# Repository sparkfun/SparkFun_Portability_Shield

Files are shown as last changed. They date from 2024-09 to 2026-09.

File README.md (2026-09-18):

SparkFun Portability Shield
========================================

SparkFun Portability Shield (https://www.sparkfun.com/products/27510)

[*SparkFun Portability Shield (DEV-27510)*](https://www.sparkfun.com/products/27510)

The SparkFun Portability Shield adds all the user interface bits needed to take a SparkFun development board into the field. A LiPo battery connector, charger, fuel gauge, and an on/off switch address your power needs. A friction-fit microSD connector allows for data logging. The 1.3in. OLED and a five-way navigation switch provide an excellent user interface. Locking 0.1in. headers along the shield's edge make it easier to solder male pins in place.

I<sup>2</sup>C is used to interface with the display, fuel gauge, and five-way navigation switch (GPIO expander PCA9554). SPI is used to communicate with the microSD card. The power switch uses an ideal diode (LM66200) to disconnect the battery from the system for a sleep current of approximately 4μA.

The Portability Shield has been designed to be usable with any compatible main board, with the [RTK Postcard](https://www.sparkfun.com/products/26916) being the first!

Head to the [Sparkfun Portability Shield Product Manual](http://docs.sparkfun.com/SparkFun_Portability_Shield/) for technical documentation.

Repository Contents
-------------------

* **/Hardware** - KiCad design files (.kicad_pro, .kicad_pcb, kicad_sch)
* **/docs** - Documentation for the github pages version of this hookup guide

License Information
-------------------

This product is _**open source**_!

Please review the LICENSE.md file for license information.

If you have any questions or concerns on licensing, please contact technical support on our [SparkFun forums](https://community.sparkfun.com).

Distributed as-is; no warranty is given.

- Your friends at SparkFun.

_<COLLABORATION CREDIT>_

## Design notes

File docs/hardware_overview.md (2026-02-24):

---
icon: material/cog
---

## OLED
The 1.3" OLED is a small, monochrome, blue on black display with a 128 x 64 dot matrix panel and a 7-bit unshifted I<sup>2</sup>C address of 0x3D. To change the I<sup>2</sup>C address to 0x3C, cut the D/C jumper on the back of the board. For more information, refer to the [datasheet](https://cdn.sparkfun.com/assets/learn_tutorials/3/0/8/SSD1306.pdf).

<figure markdown>
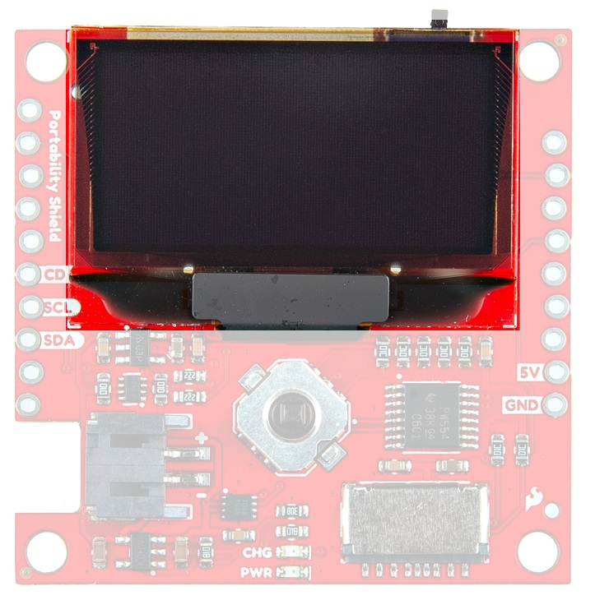
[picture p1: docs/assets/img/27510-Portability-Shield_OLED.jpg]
1.3" OLED Screen

<figcaption markdown>1.3" OLED Screen</figcaption>
</figure>

## Navigation Switch

The Navigation Switch allows for navigation of the configuration modes and menus related to the RTK or other loaded software.

<figure markdown>
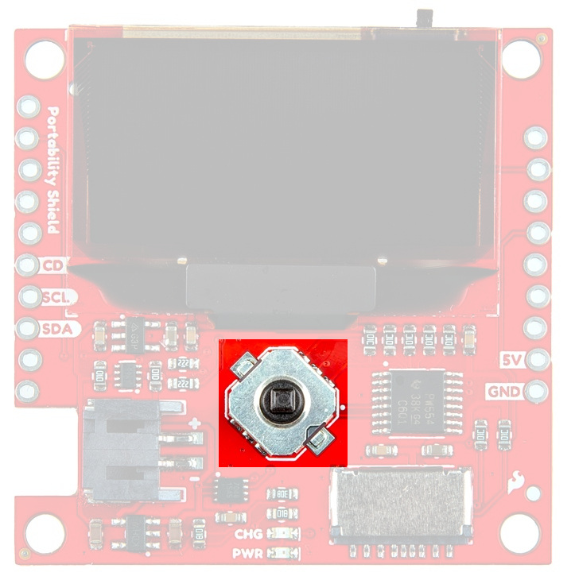
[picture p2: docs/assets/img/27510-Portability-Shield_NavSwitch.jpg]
Navigation Switch

<figcaption markdown>Navigation Switch</figcaption>
</figure>

## GPIO Expander

The TCA9554 GPIO Expander is used for I<sup>2</sup>C interfacing with the Navigation Switch, 1.3" OLED display, the fuel gauge, and the SD Card Detect. Its 7-bit unshifted address is 0x20.

<figure markdown>
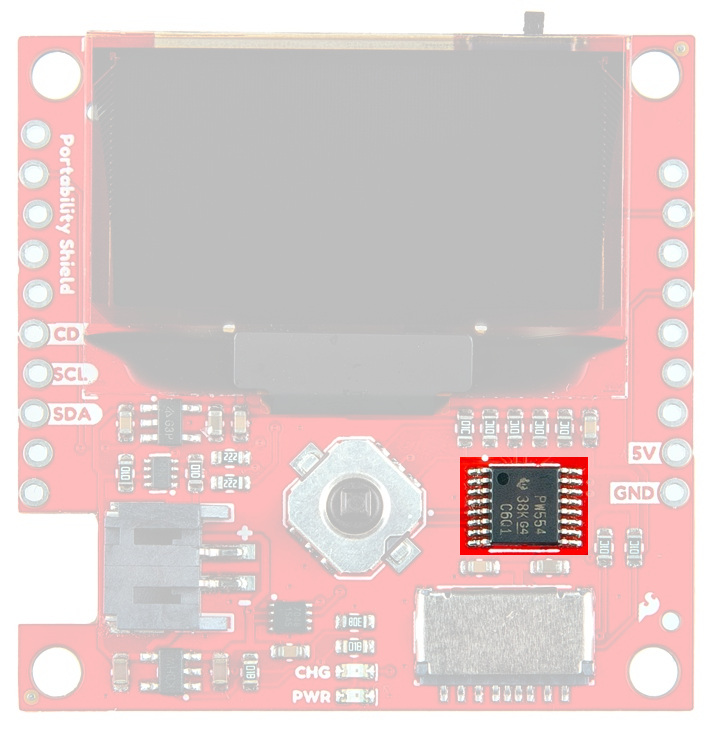
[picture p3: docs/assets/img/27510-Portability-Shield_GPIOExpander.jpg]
GPIO Expander

<figcaption markdown>GPIO Expander</figcaption>
</figure>

## Power

Power is provided by either the LiPo Battery or the 5V/GND pins. Maximum input to the board is 5V.

<figure markdown>
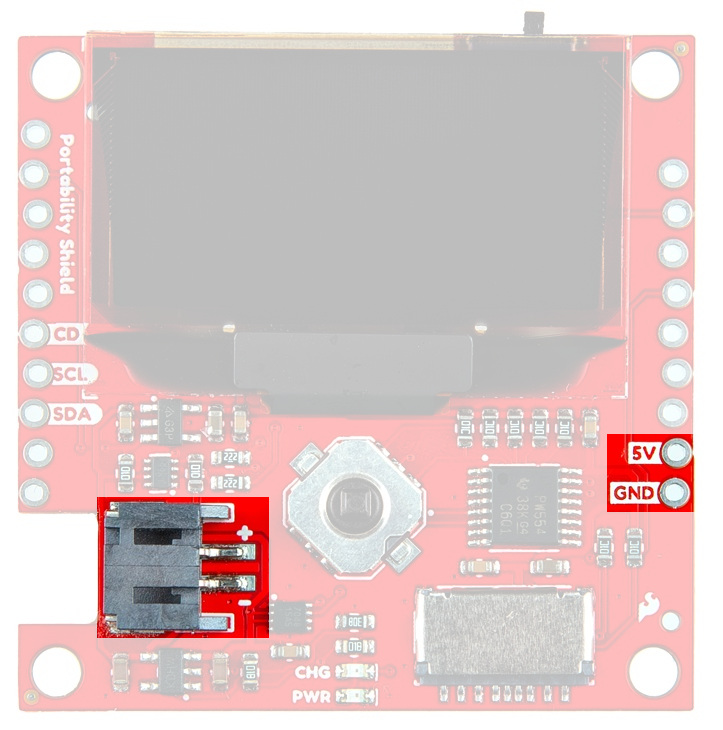
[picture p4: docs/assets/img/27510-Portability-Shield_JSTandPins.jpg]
Battery Connector/Power Pins

<figcaption markdown>Battery Connector/Power Pins</figcaption>
</figure>

## Current Measurement

There are two plated through holes available on the bottom of the board to measure current if desired.

<figure markdown>
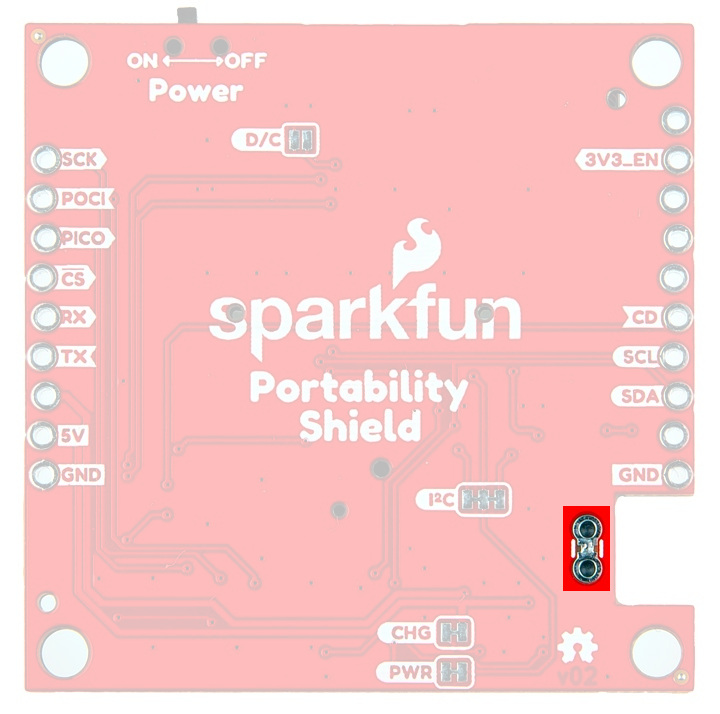
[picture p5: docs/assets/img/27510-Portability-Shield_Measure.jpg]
Current Measurement PTHs

<figcaption markdown>Current Measurement PTHs</figcaption>
</figure>

## On/Off Switch

How handy! There is an On/Off switch at the top of the board.

<figure markdown>
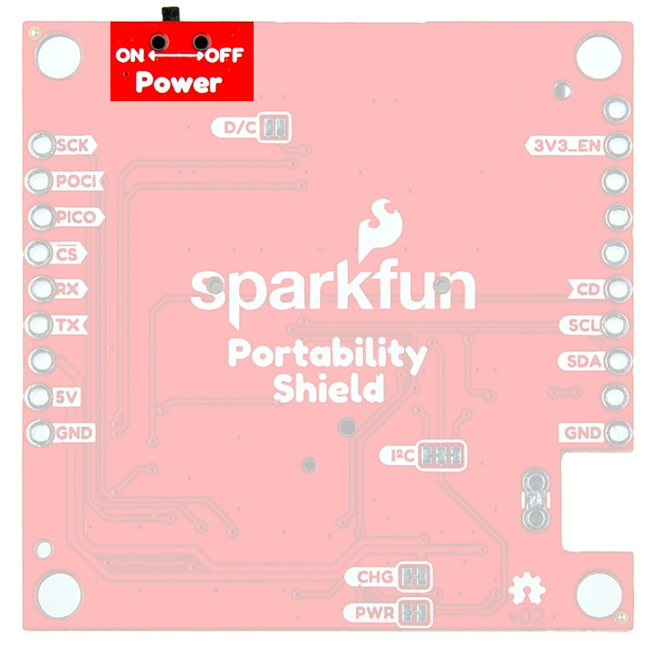
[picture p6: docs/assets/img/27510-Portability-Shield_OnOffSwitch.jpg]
On/Off Switch

<figcaption markdown>On/Off Switch</figcaption>
</figure>

## Fuel Gauge

The MAX17048 uses the Li+ battery-modeling algorithm ModelGauge™ to track the battery relative state-of-charge (SOC) continuously over widely varying charge and discharge conditions. This eliminates current-sense resistor and battery learn cycles required in traditional fuel gauges and allows for the most accurate battery percentage readings. Its 7-bit unshifted address is 0x36. For more information, you can refer to the [datasheet](https://cdn.sparkfun.com/assets/5/2/7/6/6/MAX17048-MAX17049.pdf).

<figure markdown>
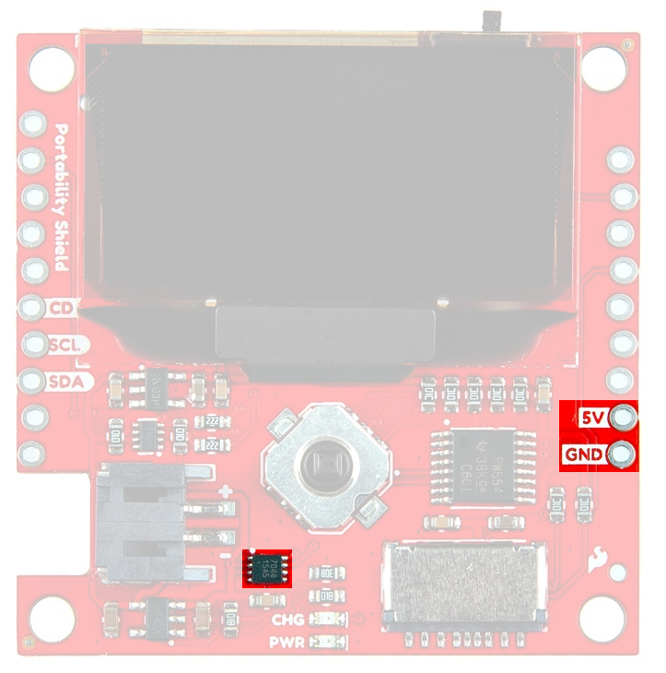
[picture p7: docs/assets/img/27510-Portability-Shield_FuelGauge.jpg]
Fuel Gauge

<figcaption markdown>Fuel Gauge</figcaption>
</figure>

## LiPo Charging Circuit

The charge circuit charges Li+ batteries at 500mA. The equation below shows our calculation for this rate.

<figure markdown>
Charge Circuit Equation
<figcaption markdown>Charge Circuit</figcaption>
</figure>

## MicroSD Card

The microSD Socket Friction Fit slot allows for data logging or easy upload of programming files.

!!! warning
	Do NOT drive the microSD card pins high if the card is not powered. Damage could occur!

<figure markdown>
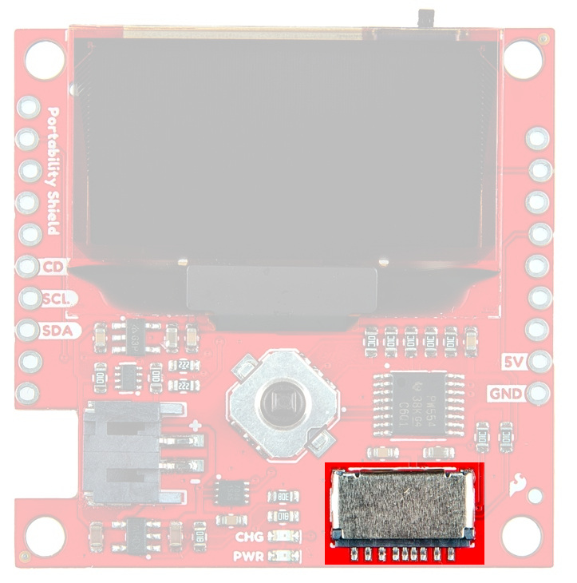
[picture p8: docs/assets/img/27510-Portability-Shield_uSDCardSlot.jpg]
microSD Card Slot

<figcaption markdown>microSD Card Slot</figcaption>
</figure>

<!-- ## Battery Charging Circuit

<figure markdown>
[![Charge Circuit Equation](assets/img/chargeCircuitEquations.jpg){ width="75%" }](assets/img/chargeCircuitEquations.jpg "Click to enlarge")
<figcaption markdown>Charge Circuit</figcaption>
</figure>

-->

## Shield Connectors

The offset PTHs allow for a snug fit when soldering headers to the board. Once male headers are soldered in, the SparkFun Portability Shield can be fit to the main board of choice.

If <b>5V</b> is present, LiPo charging commences. Below <b>5V</b>, the battery will provide VBATT to the mainboard 3.3V is not provided to mainboard - 5V/VBATT powers local 3.3V_P.

<figure markdown>
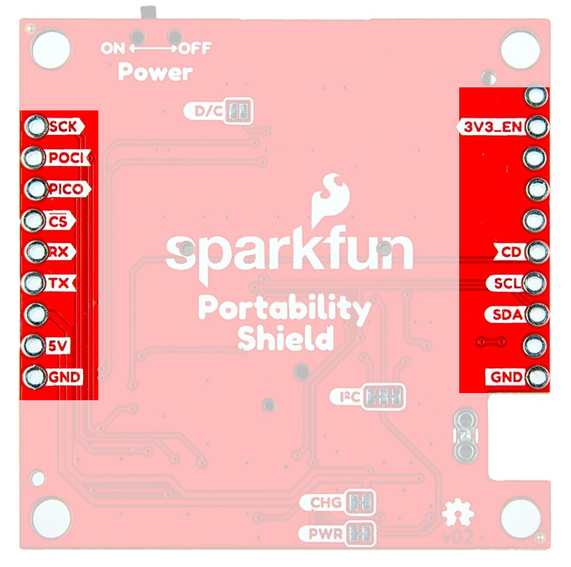
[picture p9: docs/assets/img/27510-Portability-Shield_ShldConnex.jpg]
Shield Connectors

<figcaption markdown>Shield Connectors</figcaption>
</figure>

## Jumpers

* <b>CHG:</b>
    Cutting this jumper will disconnect the power to the CHG LED on the front of the board.

* <b>PWR:</b>
    Cutting this jumper will disconnect the power to the PWR LED on the front of the board.

* <b>D/C:</b>
    Cutting this jumper will change the I<sup>2</sup>C address from 0x3D to 0x3C.
<div style="text-align: center;">
    <table>
        <tr>
            <th style="text-align: center; border: solid 1px #cccccc;">D/C
            </th>
            <th style="text-align: center; border: solid 1px #cccccc;">I2C Addr
            </th>
        </tr>
        <tr>
            <td style="text-align: center; border: solid 1px #cccccc;">0
            </td>
            <td style="text-align: center; border: solid 1px #cccccc;">0x3C
            </td>
        </tr>
        <tr>
            <td style="text-align: center; border: solid 1px #cccccc;">1
            </td>
            <td style="text-align: center; border: solid 1px #cccccc;">0x3D (default)
            </td>
        </tr>
    </table>
</div>
* <b>I<sup>2</sup>C:</b>
	The SparkFun Portability Shield has built-in 2.2k pull-up resistors on the SDA and SCL lines. These are needed for normal I<sup>2</sup>C communication. The I<sup>2</sup>C jumper has two small traces connecting the pull-ups to 3.3V. **For general use you can leave this jumper unmodified.** If you have many (over 7) devices on the I<sup>2</sup>C bus, each with their own pull up resistors, then you may want to [cut the I<sup>2</sup>C jumpers](https://learn.sparkfun.com/tutorials/how-to-work-with-jumper-pads-and-pcb-traces) to disconnect the 2.2k resistors on each Qwiic board.

<figure markdown>
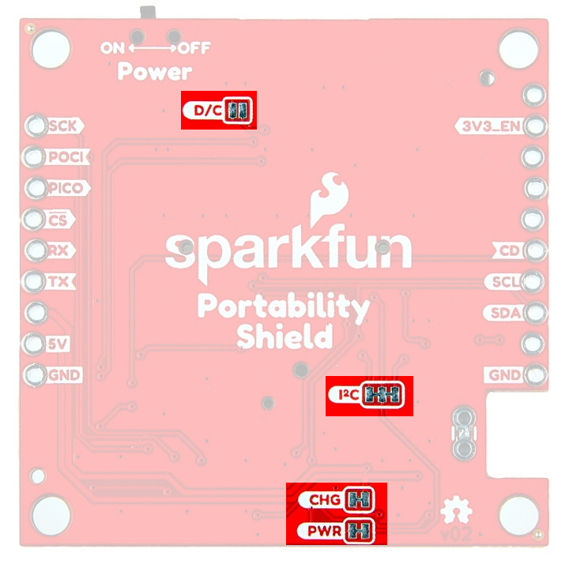
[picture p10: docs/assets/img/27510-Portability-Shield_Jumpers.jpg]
Jumpers

<figcaption markdown>Jumpers</figcaption>
</figure>

## Board Dimensions

The board dimensions are illustrated in the drawing below; the listed measurements are in millimeters.

<figure markdown>
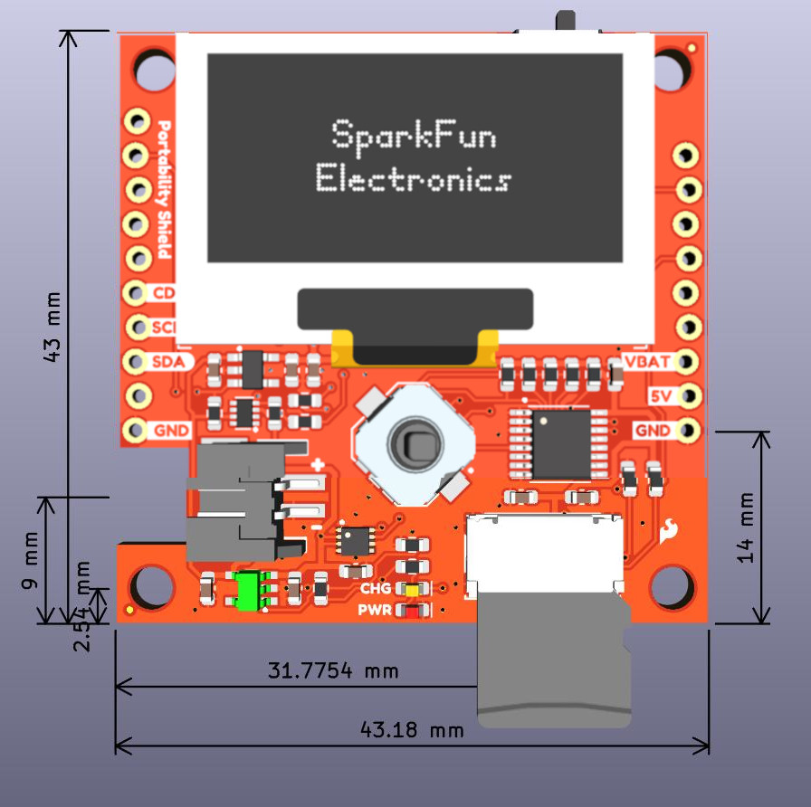
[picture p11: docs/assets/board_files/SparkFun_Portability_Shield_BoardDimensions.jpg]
Board measures 43.18mm x 43mm

<figcaption markdown>SparkFun Portability Shield Board Dimensions</figcaption>
</figure>

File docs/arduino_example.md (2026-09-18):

---
icon: simple/arduino
---

###Example 1: Navigation Switch

This example demonstrates how to use the navigation switch and detect if the SD card is inserted. The !INT pin of the GPIO expander IC (PCA9554) triggers an interrupt any time a button is pressed or an SD card is inserted/removed.

The code for this example can be found in the [Firmware](../Firmware/Example1_NavigationSwitch/) folder of this repository. Alternatively, you can expand the link below and copy and paste the code into a shiny new Arduino sketch:

??? "Example 1 Arduino Code"
	```cpp
	--8<-- "https://raw.githubusercontent.com/sparkfun/SparkFun_Portability_Shield/refs/heads/main/Firmware/Example1_NavigationSwitch/Example1_NavigationSwitch.ino"
	```

One thing to note is that you will also need to install the SparkFun I2C Expander Arduino Library if you haven't already. You can search the library from within the Arduino Library manager, download the zip from [the GitHub Repository](https://github.com/sparkfun/SparkFun_I2C_Expander_Arduino_Library/archive/refs/heads/main.zip) and install it manually, or you can click the link from within the code. Clicking the link will show something like the following:

<figure markdown>
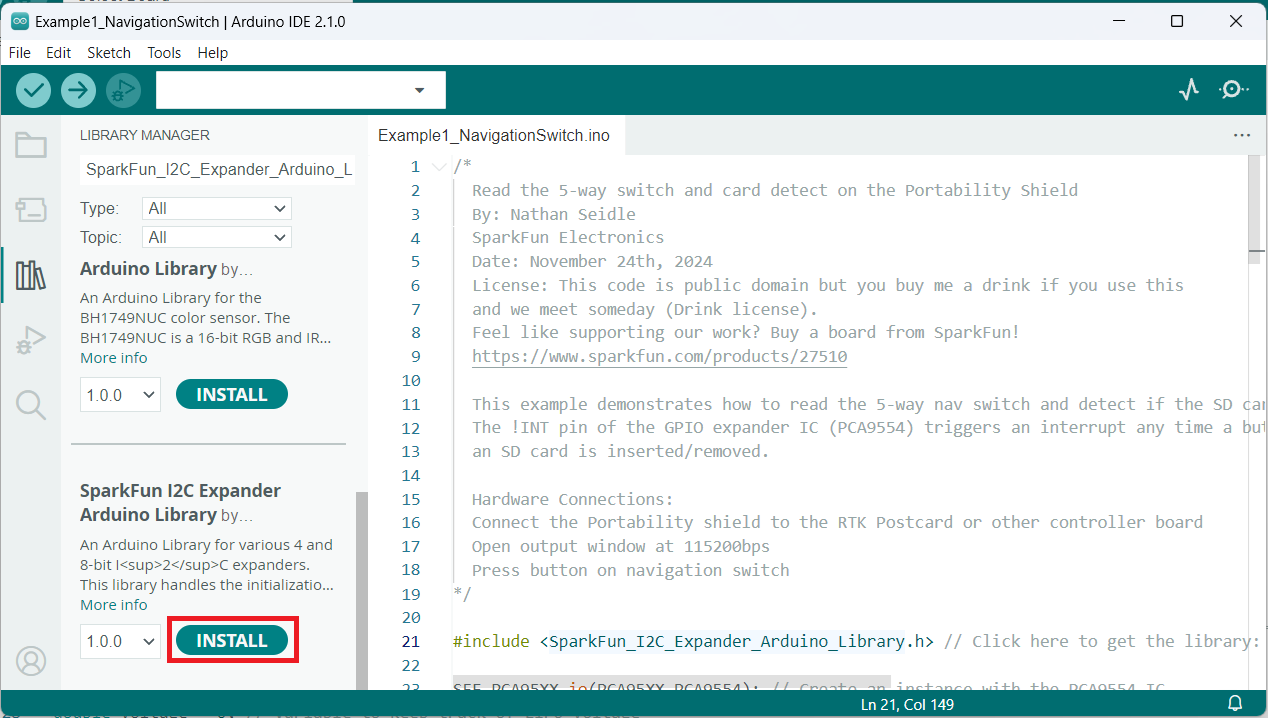
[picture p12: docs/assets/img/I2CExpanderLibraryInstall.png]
SparkFun I2C Expander Arduino Library Install

<figcaption markdown>SparkFun I2C Expander Arduino Library Install</figcaption>
</figure>

Make sure you've selected the correct board (in this case, you will need to use ESP32 Dev Module from espressif) and port in the Tools menu and then hit the upload button. Once the code has finished uploading, go ahead and open a [Serial Monitor](https://learn.sparkfun.com/tutorials/terminal-basics). You should see something similar to the following.

<figure markdown>
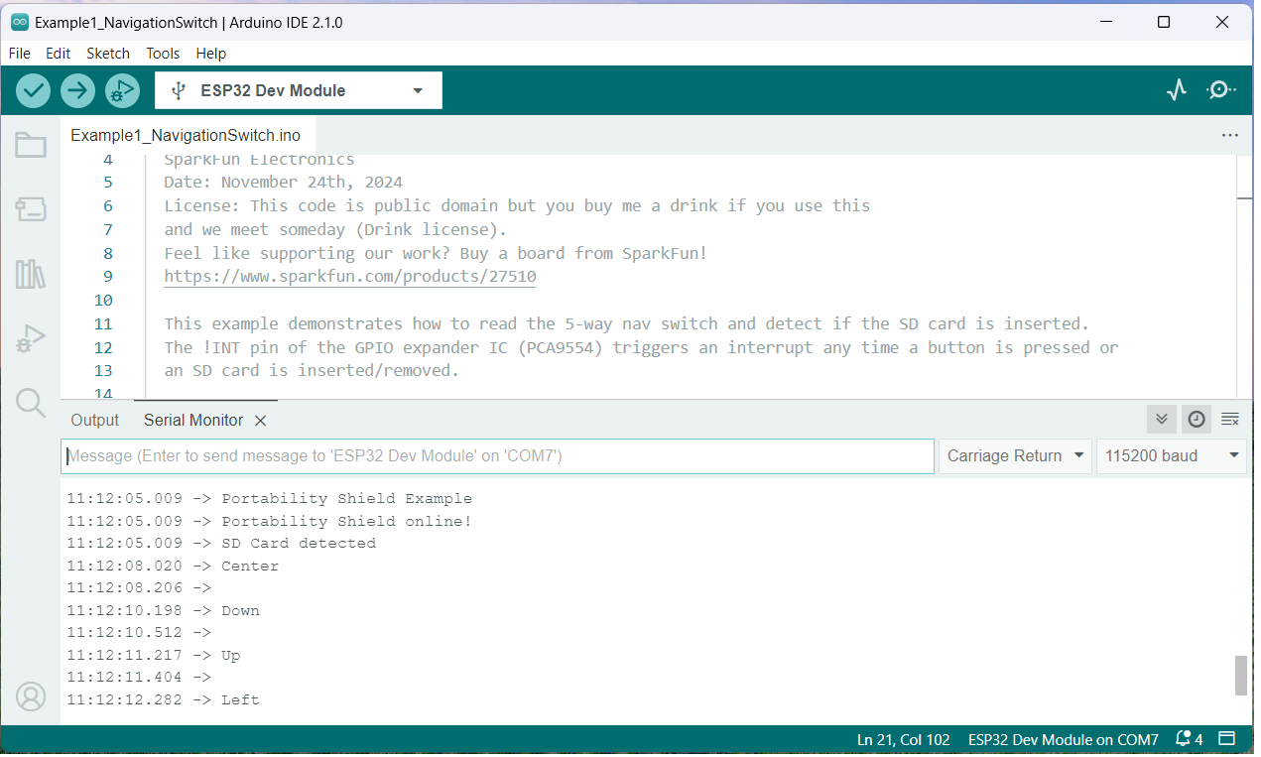
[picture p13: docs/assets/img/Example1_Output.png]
Arduino Example 1 Output

<figcaption markdown>Example 1 Output</figcaption>
</figure>

###Example 2: Fuel Gauge
This file demonstrates the simple API of the SparkFun MAX17043 Arduino library. Make sure you have a LiPo battery plugged into the JST port.

The code for this example can be found in the [Firmware](../Firmware/Example2_FuelGauge/) folder of this repository. Alternatively, you can expand the link below and copy and paste the code into a shiny new Arduino sketch:

??? "Example 2 Arduino Code"
    ```cpp
    --8<-- "https://github.com/sparkfun/SparkFun_Portability_Shield/raw/refs/heads/main/Firmware/Example2_FuelGauge/Example2_FuelGauge.ino"
    ```

You will also need to install the SparkFun MAX1704x Fuel Gauge Arduino Library if you haven't already. You can search the library from within the Arduino Library manager, download the zip from [the GitHub Repository](https://github.com/sparkfun/SparkFun_MAX1704x_Fuel_Gauge_Arduino_Library/archive/refs/heads/main.zip) and install it manually, or you can click the link from within the code. Clicking the link will show something like the following:

<figure markdown>
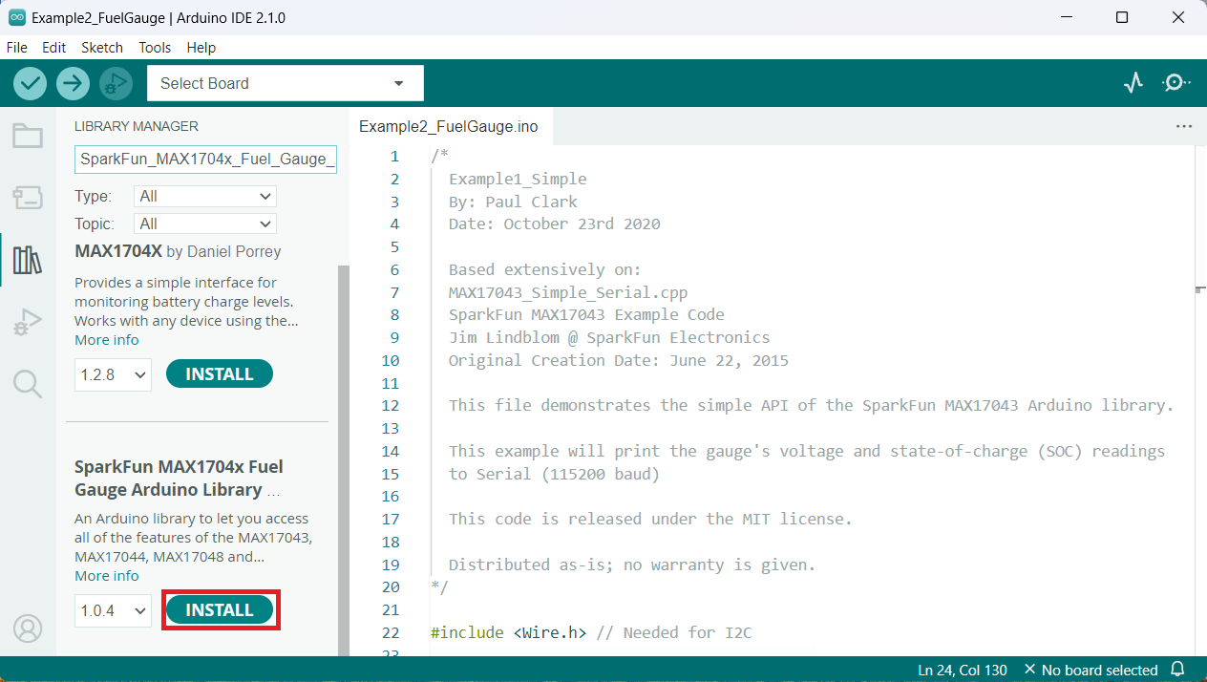
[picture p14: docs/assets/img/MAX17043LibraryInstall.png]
SparkFun MAX1704x Fuel Gauge Arduino Library Install

<figcaption markdown>SparkFun MAX1704x Fuel Gauge Arduino Library Install</figcaption>
</figure>

Make sure you've selected the correct board and port in the Tools menu and then hit the upload button. Once the code has finished uploading, go ahead and open a [Serial Monitor](https://learn.sparkfun.com/tutorials/terminal-basics) at 115200 baud. You should see the gauge's voltage and state-of-charge (SOC) readings, similar to the following:

<figure markdown>
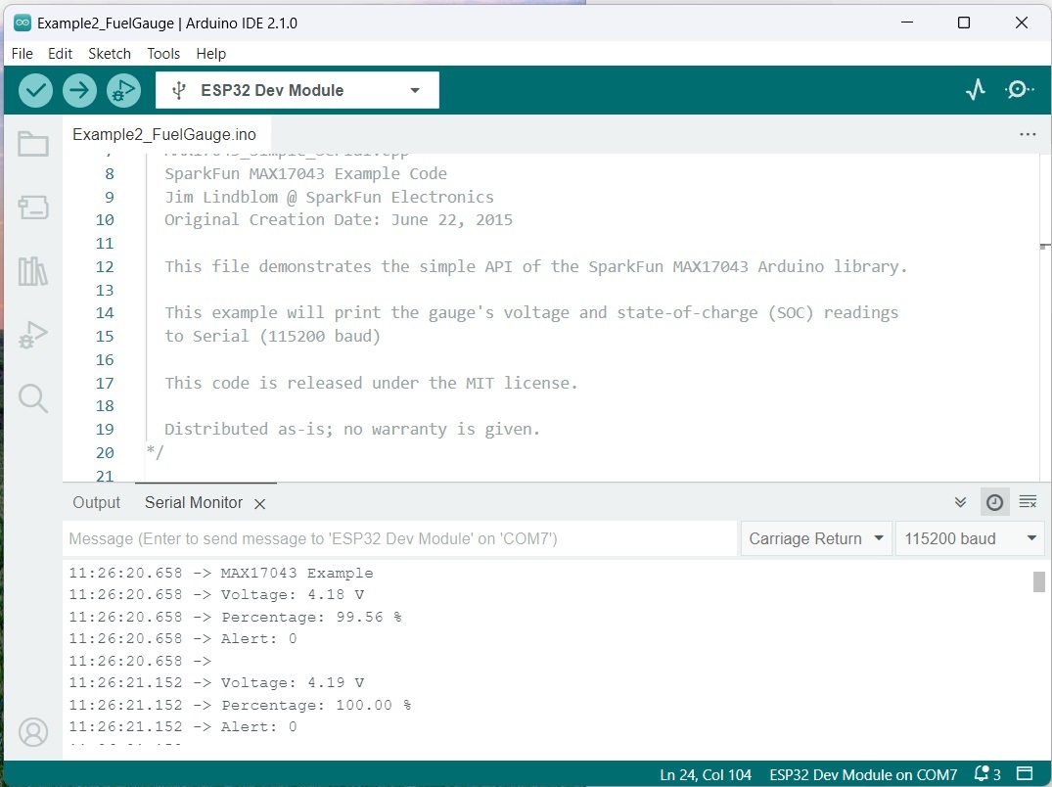
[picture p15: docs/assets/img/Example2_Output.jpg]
Arduino Example 2 Output

<figcaption markdown>Example 2 Output</figcaption>
</figure>

###Example 3: Display

This example demonstrates how to display on the 1.3" OLED and read the fuel gauge. You should have the Portability Shield connected to the RTK Postcard or other controller and a LiPo battery plugged into the JST port.

The code for this example can be found in the [Firmware](../Firmware/Example3_Display/) folder of this repository. Alternatively, you can expand the link below and copy and paste the code into a shiny new Arduino sketch:

??? "Example 3 Arduino Code"
	```cpp
	--8<-- "https://raw.githubusercontent.com/sparkfun/SparkFun_Portability_Shield/refs/heads/main/Firmware/Example3_Display/Example3_Display.ino"
	```

You will also need both the SparkFun Qwiic OLED Arduino Library as well as the SparkFun MAX1704x Fuel Gauge Arduino Library. If you haven't already installed these, you can search them from within the Arduino Library manager and install them from there. Alternatively, you can download the zips from their respective GitHub Repositories [here(Fuel Gauge)](https://github.com/sparkfun/SparkFun_MAX1704x_Fuel_Gauge_Arduino_Library/archive/refs/heads/main.zip) and [here(Qwiic OLED)](https://github.com/sparkfun/SparkFun_Qwiic_OLED_Arduino_Library/archive/refs/heads/main.zip), and install them manually.

Make sure you've selected the correct board and port in the Tools menu and then hit the upload button. Once the code has finished uploading, you should see the gauge's voltage and state-of-charge (SOC) readings, similar to the the output for Example 2.
The 1.3" OLED display should show a bouncing box like so:

<figure markdown>
Arduino Example 3 Output
<figcaption markdown>Example 3</figcaption>
</figure>

###Example 4: SD Card

This example will mount an SD card, analyze the type of card, and output the analysis via the Serial Monitor.

Go ahead and connect the Portability Shield to the RTK Postcard or other controller board. Insert a microSD card into the socket. Cards up to 512GB should work.

The code for this example can be found in the [Firmware](../Firmware/Example4_SD/) folder of this repository. Alternatively, you can expand the link below and copy and paste the code into a shiny new Arduino sketch:

??? "Example 4 Arduino Code"
	```cpp
	--8<-- "https://github.com/sparkfun/SparkFun_Portability_Shield/raw/refs/heads/main/Firmware/Example4_SD/Example4_SD.ino"
	```

You will also need to install the SDFat Arduino Library if you haven't already. You can search the library from within the Arduino Library manager, download the zip from [the GitHub Repository](https://github.com/sparkfun/SparkFun_Qwiic_OLED_Arduino_Library/archive/refs/heads/main.zip) and install it manually, or you can click the link from within the code.

Make sure you've selected the correct board and port in the Tools menu and then hit the upload button. Once the code has finished uploading, go ahead and open a [Serial Monitor](https://learn.sparkfun.com/tutorials/terminal-basics) at 115200 baud. Once you type in any key in the Message Field and send it, the code will analyze the SD card and output something similar to the following:

<figure markdown>
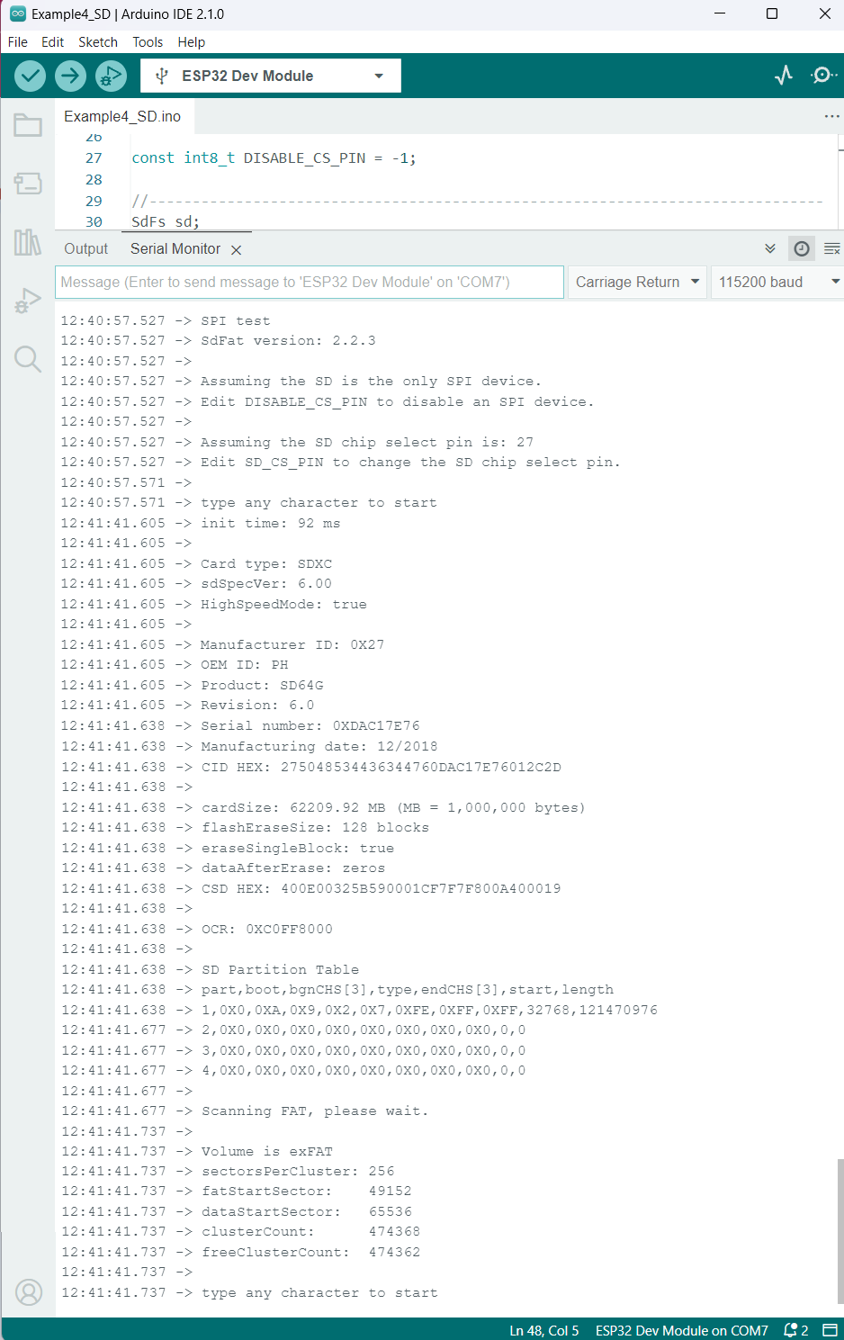
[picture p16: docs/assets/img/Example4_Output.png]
Arduino Example 4 Output

<figcaption markdown>Example 4 Output</figcaption>
</figure>

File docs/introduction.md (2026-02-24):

---
icon: material/book-open-page-variant
---

<div class="grid cards desc" markdown>

-    <a href="https://www.sparkfun.com/products/27510">
    **SparkFun Portability Shield**<br>
    **SKU:** DEV-27510

    ---

    <figure markdown>
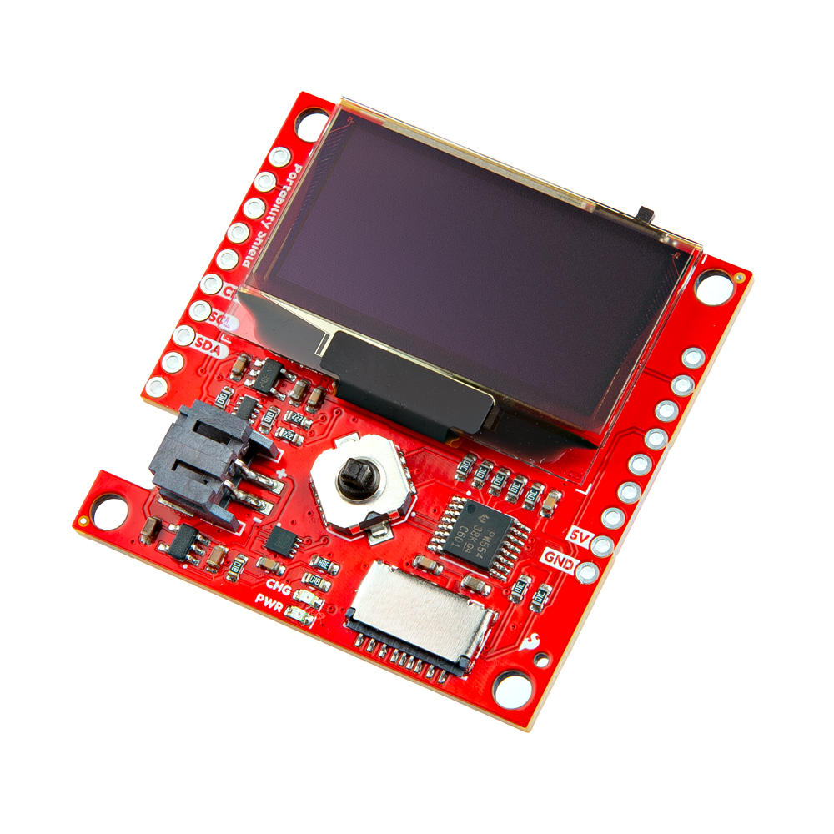
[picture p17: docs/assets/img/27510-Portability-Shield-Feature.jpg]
Product Thumbnail
    
    </figure></a>

- The SparkFun Portability Shield adds all the user interface bits needed to take a SparkFun dev board into the field. A LiPo battery connector, charger, fuel gauge, and an on/off switch take care of your power needs. A friction-fit microSD connector allow for datalogging. The 1.3" OLED and a 5-way navigation switch allow for an excellent user interface. Locking 0.1" headers along the edge of the shield make it easier to solder male pins in place.

    I<sup>2</sup>C is used to interface to the display, fuel gauge, and the 5 way navigation switch (GPIO expander PCA9554), SPI is used to communicate with the microSD card. The power switch uses an ideal diode (LM66200) to disconnect the battery from the system for a sleep current of approximately 4μA.

    <article style="text-align: center;" markdown>
    [Purchase from SparkFun :fontawesome-solid-cart-plus:{ .heart }](https://www.sparkfun.com/products/27510){ .md-button .md-button--primary }
    </article>

</div>

## Required Materials

To follow along with this tutorial, you will need the following materials. You may not need everything, depending on what you have. Add it to your cart, read through the guide, and adjust the cart as necessary.

<div class="grid cards" markdown>

-   <a href="https://www.sparkfun.com/sparkfun-portability-shield.html">
    <figure markdown>
    Product Thumbnail
    </figure>

    ---

    **SparkFun Portability Shield**<br>
    DEV-27510</a>

-   <a href="https://www.sparkfun.com/sparkfun-rtk-postcard.html">
    <figure markdown>
    Product Thumbnail
    </figure>

    ---

    **SparkFun RTK Postcard**<br>
    GPS-26916</a>

-   <a href="https://www.sparkfun.com/header-1x20-male-0-1.html">
    <figure markdown>
    Product Thumbnail
    </figure>

    ---

    **Header - 1x20 (Male, 0.1")**<br>
    PRT-29760</a>

-   <a href="https://www.sparkfun.com/lithium-ion-battery-850mah.html">
    <figure markdown>
    Product Thumbnail
    </figure>

    ---

    **Lithium Ion Battery - 850mAh**<br>
    PRT-13854</a>

-   <a href="https://www.sparkfun.com/microsd-card-1gb-class-4.htmll">
    <figure markdown>
    Product Thumbnail
    </figure>

    ---

    **microSD Card - 1GB (Class 4)**<br>
    COM-15107</a>

</div>

## Suggested Reading

Below are a few tutorials that may help users familiarize themselves with various aspects of the board.

<div class="grid cards hide col-4" markdown align="center">

-   <a href="https://learn.sparkfun.com/tutorials/what-is-gps-rtk">
    <figure markdown>
    What is GPS RTK
    </figure>
    </a>
    <a href="https://learn.sparkfun.com/tutorials/what-is-gps-rtk">**What is GPS RTK**
    </a>
-   <a href="https://docs.sparkfun.com/SparkFun_RTK_Everywhere_Firmware/">
    <figure markdown>
    SparkFun RTK Everywhere Product Manual
    </figure>
    </a>
    <a href="https://docs.sparkfun.com/SparkFun_RTK_Everywhere_Firmware/">**SparkFun RTK Everywhere Product Manual**
    </a>

</div>

<!--
<center>
<div align="center">
    <div style="top:5px;left:5px;background-color:Gray;position:relative">
        <div style="top:-5px;left:-5px;background-color:#ffffff;position:relative;border:1px solid black;">
            <a href="https://www.sparkfun.com/qwiic"><img src="https://cdn.sparkfun.com/assets/custom_pages/2/7/2/qwiic-logo.png" alt="Qwiic Connect System" title="Qwiic Connect System"></a>
        </div>
    </div>
</div>
</center>

The SparkFun Portability Shield takes advantage of the [Qwiic connect system](https://www.sparkfun.com/qwiic). We recommend familiarizing yourself with the **Logic Levels** and **I<sup>2</sup>C** tutorials.  Click on the banner above to learn more about [Qwiic products](https://www.sparkfun.com/qwiic).

<center>
    <iframe width="600" height="327" src="https://www.youtube.com/embed/x0RDEHqFIF8" title="SparkFun's Qwiic Connect System" frameborder="0" allow="accelerometer; autoplay; clipboard-write; encrypted-media; gyroscope; picture-in-picture" allowfullscreen></iframe>
</center>
 -->

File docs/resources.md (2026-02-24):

<!-- This section should include all the relevant documentation and product files (Eagle files, schematic, datasheet(s), landing pages, etc. and any relevant tutorials to go beyond the Hookup Guide.) -->

For more resources related to the SparkFun Portability Shield, check out the links listed here:

* [Product Page](https://www.sparkfun.com/products/27510)
* [Schematic](assets/board_files/SparkFun_Portability_Shield_Schematic.pdf) (PDF)
* [KiCad Files](assets/board_files/SparkFun_Portability_Shield_KiCadFiles.zip) (ZIP)
* [Board Dimensions](assets/board_files/SparkFun_Portability_Shield_BoardDimensions.jpg)
* [Hardware GitHub Respository](https://github.com/sparkfun/SparkFun_Portability_Shield)

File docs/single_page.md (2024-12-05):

---
hide:
  - navigation
  - toc
icon: fontawesome/solid/scroll
---

--8<-- "./docs/introduction.md:5"

# Hardware Overview
--8<-- "./docs/hardware_overview.md:5"

# Hardware Assembly
--8<-- "./docs/hardware_assembly.md:5"

# Troubleshooting Tips
--8<-- "./docs/troubleshooting.md:5"

# Resources:
--8<-- "./docs/resources.md"

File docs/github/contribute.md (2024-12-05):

# Contribute: Make an Augmentation!
Spot an improvement opportunity? Feel free to contribute to our open-source design and documentation. 

## :material-file-document-multiple:&nbsp;Improve our Documentation
All of this documentation can be modified by you! Please help us make it better.

* These pages are contained in the [`docs` folder](https://github.com/sparkfun/SparkFun_Portability_Shield/tree/main/docs) of the [SparkFun Portability Shield repository](https://github.com/sparkfun/SparkFun_Portability_Shield/tree/main).

<!-- ### :material-source-pull:&nbsp;Submit a Correction -->
### Submit a Correction

1. With a GitHub account, [fork this repository](https://github.com/sparkfun/SparkFun_Portability_Shield/fork).
2. Add your corrections or improvements to the markdown file.
3. File a pull request with your changes, and enjoy making the ~~words~~ ~~worlds~~ world a better place.
	* Once received, the documentation specialist will automatically be notified.
	* We will review your suggested improvements to make sure they are correct and fit within our documentation standards.

## :material-cog:&nbsp;Improve our Hardware Design
All of our designs are open-source! Please help us make it better.

* Our board design files are contained in the [`Hardware` folder](https://github.com/sparkfun/SparkFun_Portability_Shield/tree/main/Hardware) of the [SparkFun Portability Shield repository](https://github.com/sparkfun/SparkFun_Portability_Shield/tree/main).

<!-- ### :material-source-pull:&nbsp;Submit a Design Enhancement -->
### Submit a Design Enhancement

1. With a GitHub account, [fork this repository](https://github.com/sparkfun/SparkFun_Portability_Shield/fork).
2. Add your design augmentation(s)
3. File a pull request with your changes, and enjoy making the ~~words~~ ~~worlds~~ world a better place.
	1. Once received, the engineer in charge of the original design will automatically be notified.
	2. We will review your suggested improvement(s) to verify that they are within our board design standards and meet our product design requirements.
	3. If approved, we will flag these changes for our next board revision. Congrats! 🍻

		!!! info
			Even if your suggestion is accepted, these changes may not be immediately available for purchase. We may have to cycle through our current product inventory first.

## Contributors&nbsp;:clap:
Let's provide some recognition to the contributors for this project!

GitHub Contributors Image
<br>


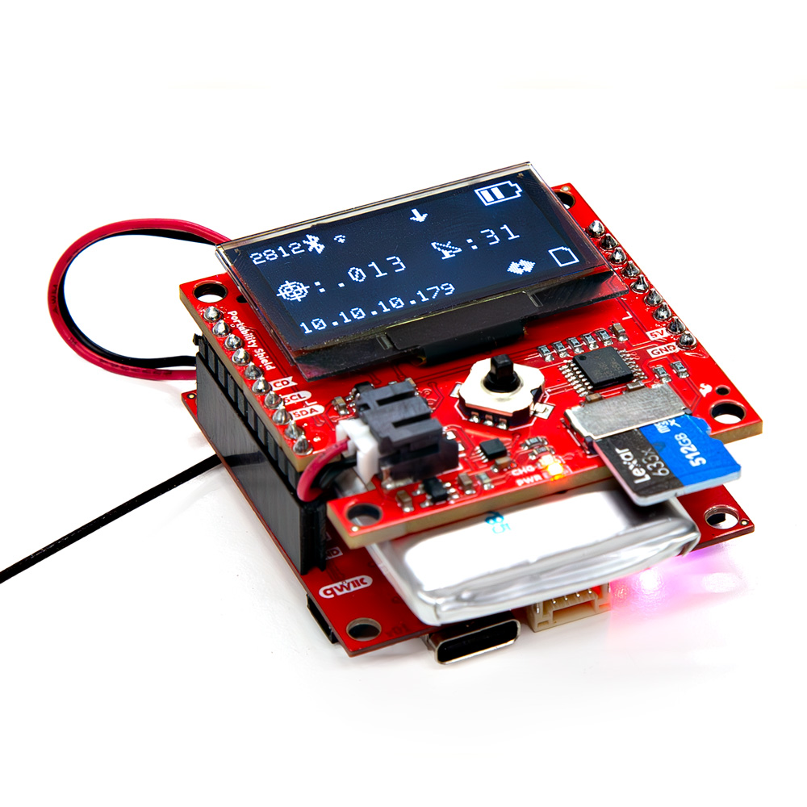
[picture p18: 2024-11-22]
docs/assets/img/27510-Portability-Shield-Action-square.jpg

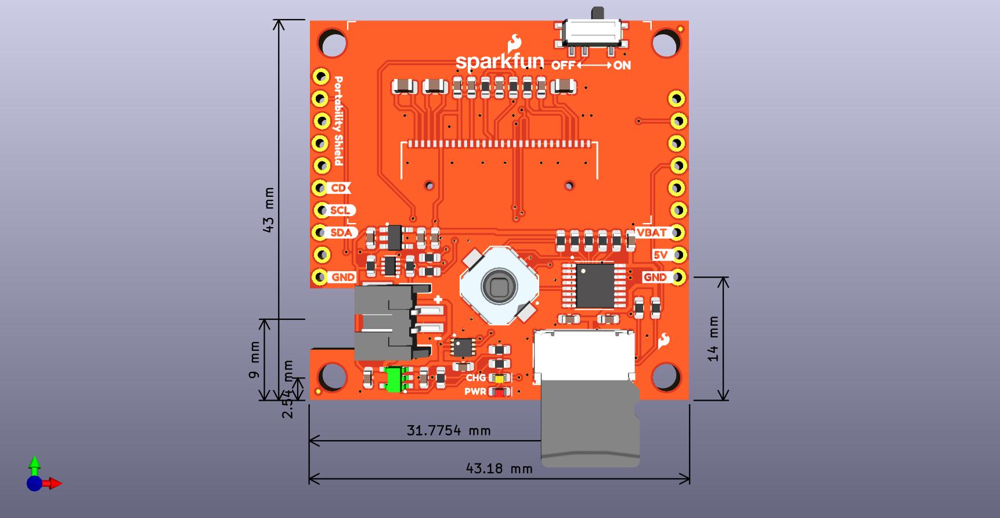
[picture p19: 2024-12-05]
docs/assets/board_files/SparkFun_Portability_Shield.jpg

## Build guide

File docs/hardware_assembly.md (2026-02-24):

---
icon: fontawesome/solid/screwdriver-wrench
---

The Portability Shield has been designed to be usable with any compatible main board. Here we have soldered in headers and it is plugged into the [RTK Postcard](https://www.sparkfun.com/products/26916). Note that there is an antenna attached to the module, as well as a LiPo battery plugged into the JST port.

<figure markdown>
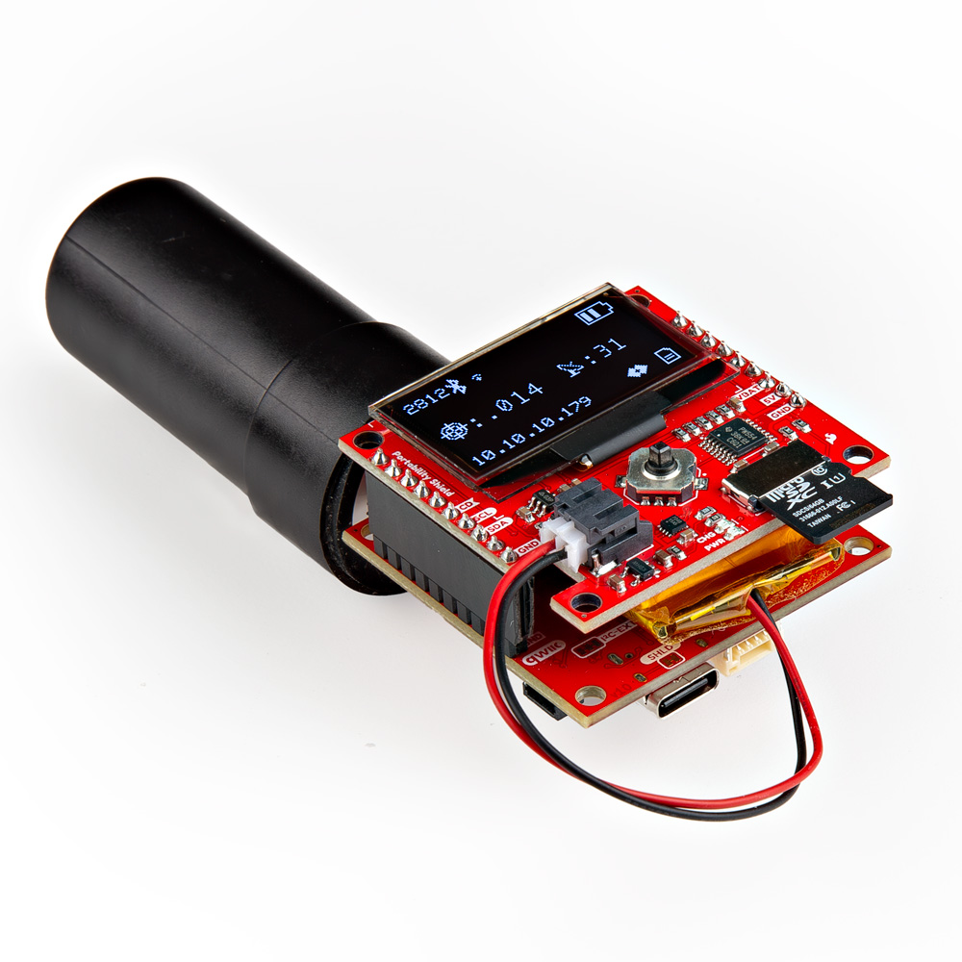
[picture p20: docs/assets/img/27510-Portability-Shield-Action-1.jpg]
SparkFun Portability Shield and RTK Postcard

<figcaption markdown>SparkFun Portability Shield and RTK Postcard</figcaption>
</figure>

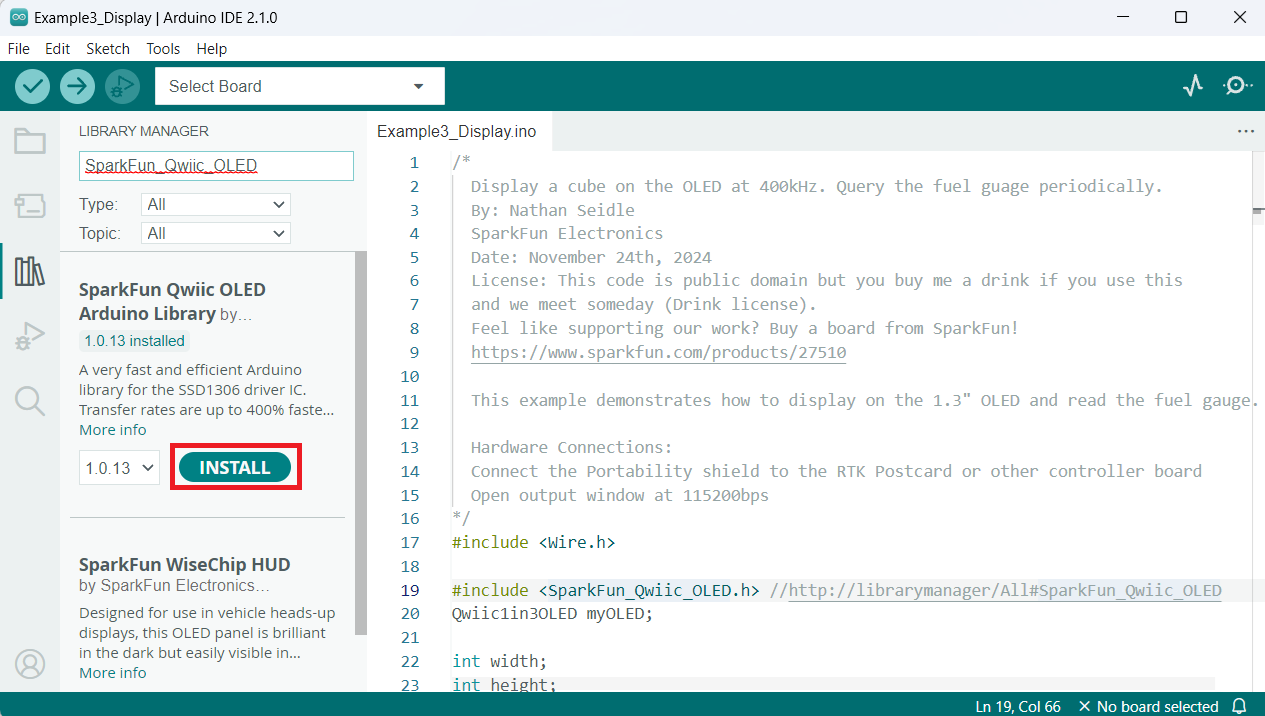
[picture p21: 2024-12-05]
docs/assets/img/QwiicOLEDLibraryInstall.png

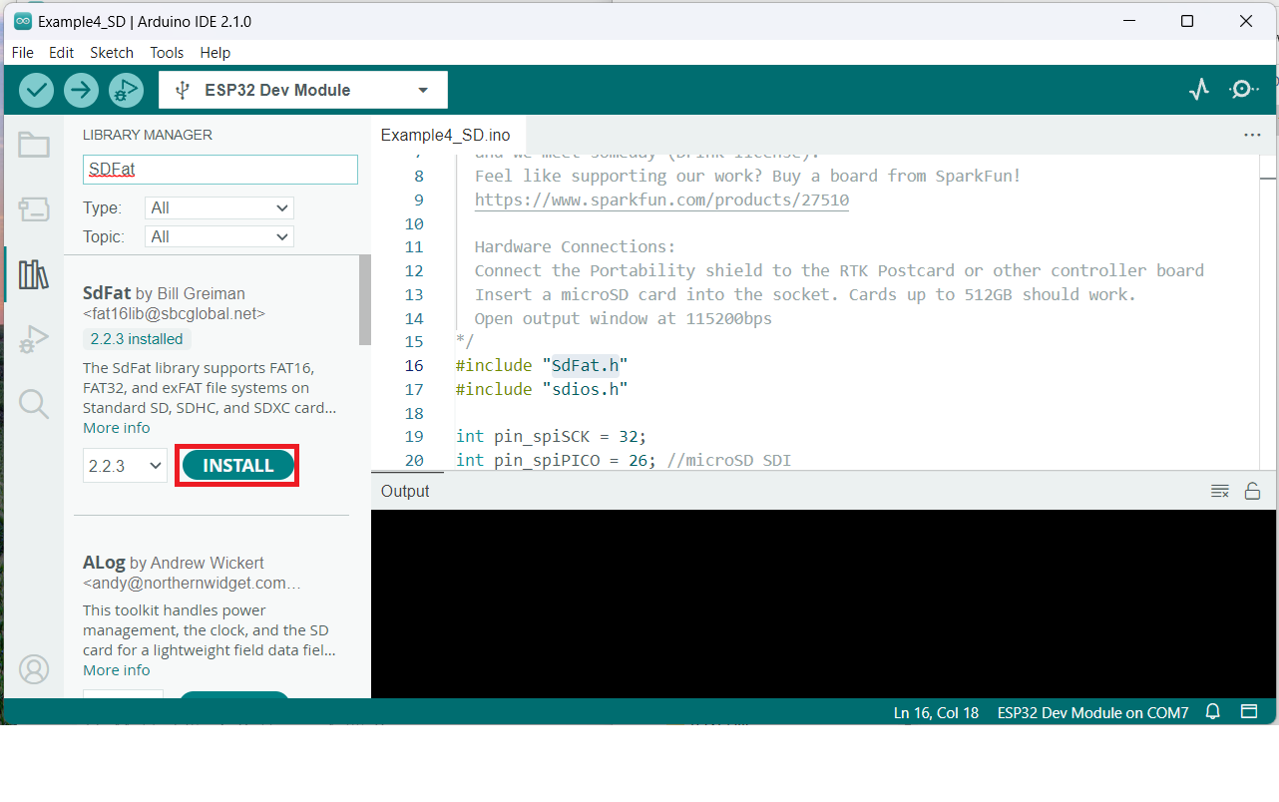
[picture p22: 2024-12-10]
docs/assets/img/SDFatLibraryInstall.png

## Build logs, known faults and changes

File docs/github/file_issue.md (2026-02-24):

# Did we make a mistake?

Spot something wrong? Please let us know. 

<!-- Technical Assistance Box -->
!!! warning "Need Help?"
	If you need technical assistance or more information on a product that is not working as you expected, we recommend heading on over to the [SparkFun Forums](https://community.sparkfun.com).

	!!! info "Account Registration Required"
		If this is your first visit to our forum, you'll need to create a [Forum Account](https://community.sparkfun.com/signup) to post questions.

## Discrepancies in the Documentation

All of our documentation can be modified by you! Please help us make it better.

* The documentation files for these pages are contained in the [`docs` folder](https://github.com/sparkfun/SparkFun_Portability_Shield/tree/main/docs) of the [SparkFun Portability Shield repository](https://github.com/sparkfun/SparkFun_Portability_Shield/tree/main).

### 🔍 Spot something wrong?

If a section of the documentation is incorrect, please [open an issue](https://github.com/sparkfun/SparkFun_Portability_Shield/issues) and let us know.

### Do you have a suggested correction?

1. With a GitHub account, [fork this repository](https://github.com/sparkfun/SparkFun_Portability_Shield/fork).
2. Add your correction(s) or improvement(s) to the markdown file(s)
3. File a pull request with your changes, and enjoy making the ~~words~~ ~~worlds~~ world a better place.
	* Once received, the documentation specialist will automatically be notified.
	* We will review your suggested improvement(s) to make sure they are correct and fit within our documentation standards.

## Problems in the Hardware Design

All of our designs are open-source! Please help us make it better.

* Our board design files are contained in the [`Hardware` folder](https://github.com/sparkfun/SparkFun_Portability_Shield/tree/main/Hardware) of the [SparkFun Portability Shield repository](https://github.com/sparkfun/SparkFun_Portability_Shield/tree/main).

### Does something not make sense? 🤔

If part of the design is confusing, please [open an issue](https://github.com/sparkfun/SparkFun_Portability_Shield/issues) and let us know.

### Did we forget to include an important function of the board? 🤦

If part of the board's functionality is missing, please [open an issue](https://github.com/sparkfun/SparkFun_Portability_Shield/issues) and file a feature request.

!!! tip "Design Considerations"
	Please keep in mind that we may intentionally exclude certain functions of the board to meet our product design requirements.
	
	* *For example, our Qwiic Micro boards are intended to fit on a small board layout and only use I<sup>2</sup>C communication; therefore, we may not have the SPI and interrupt pins available for users.*

### Do you wish to contribute directly to improving the board design?

1. With a GitHub account, [fork this repository](https://github.com/sparkfun/SparkFun_Portability_Shield/fork).
2. Add your design augmentation(s)
3. File a pull request with your changes, and enjoy making the ~~words~~ ~~worlds~~ world a better place.
	1. Once received, the engineer in charge of the original design will automatically be notified.
	2. We will review your suggested improvement(s) to verify that they are within our board design standards and meet our product design requirements.
	3. If approved, we will flag these changes for our next board revision. Congrats! 🍻

		!!! info
			Even if your suggestion is accepted, these changes may not be immediately available for purchase. We may have to cycle through our current product inventory first.

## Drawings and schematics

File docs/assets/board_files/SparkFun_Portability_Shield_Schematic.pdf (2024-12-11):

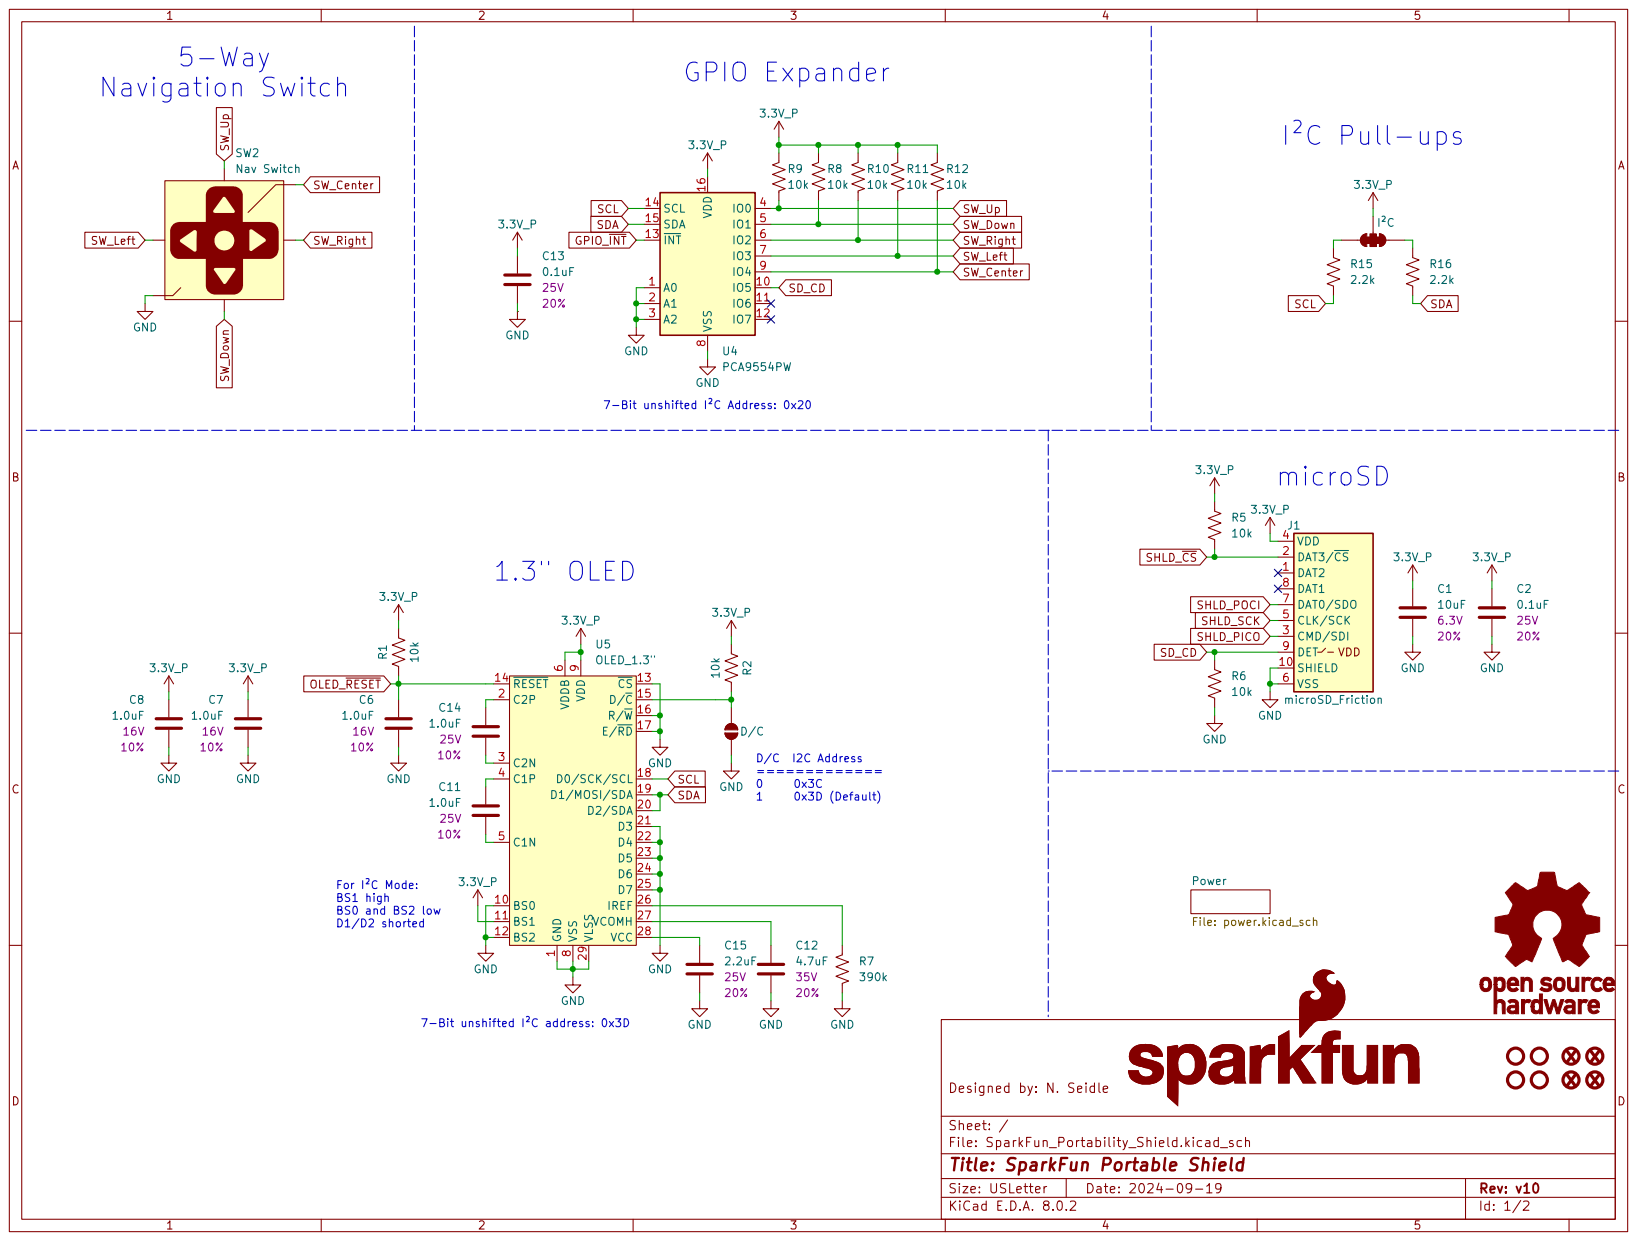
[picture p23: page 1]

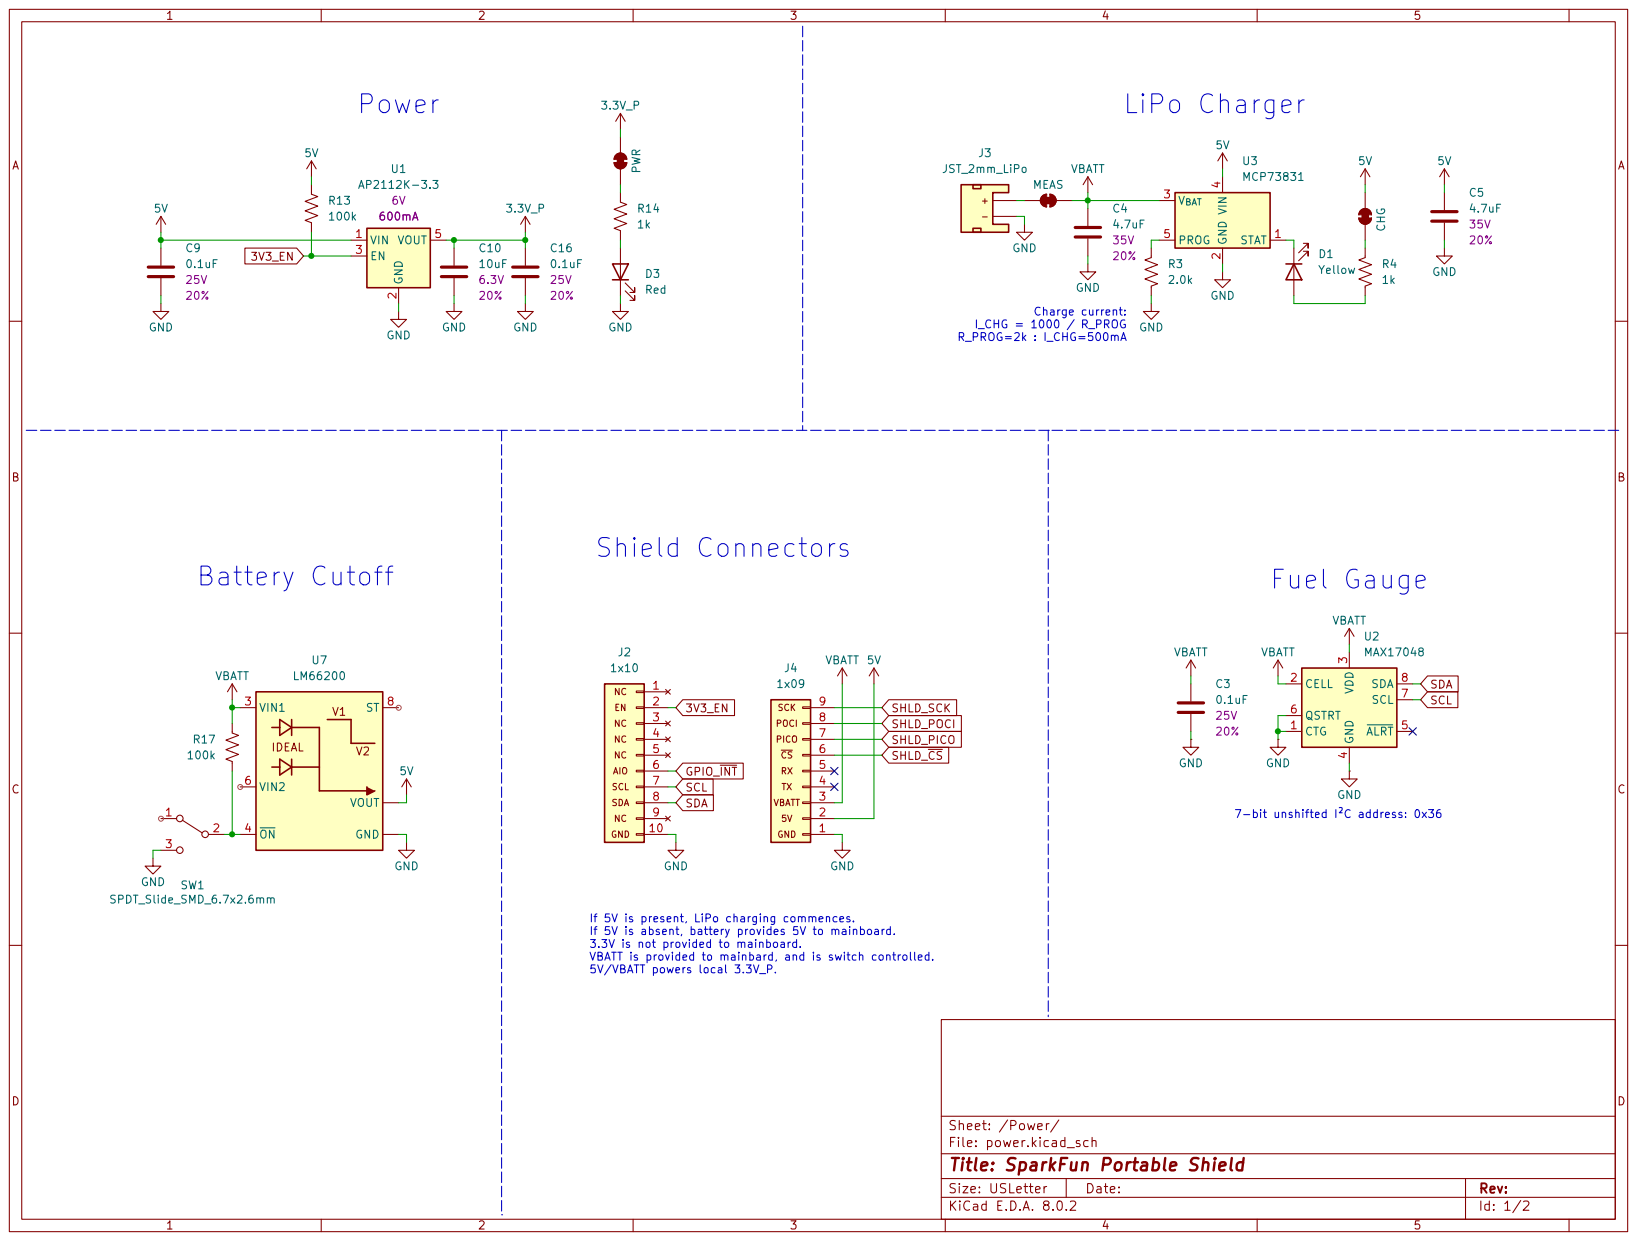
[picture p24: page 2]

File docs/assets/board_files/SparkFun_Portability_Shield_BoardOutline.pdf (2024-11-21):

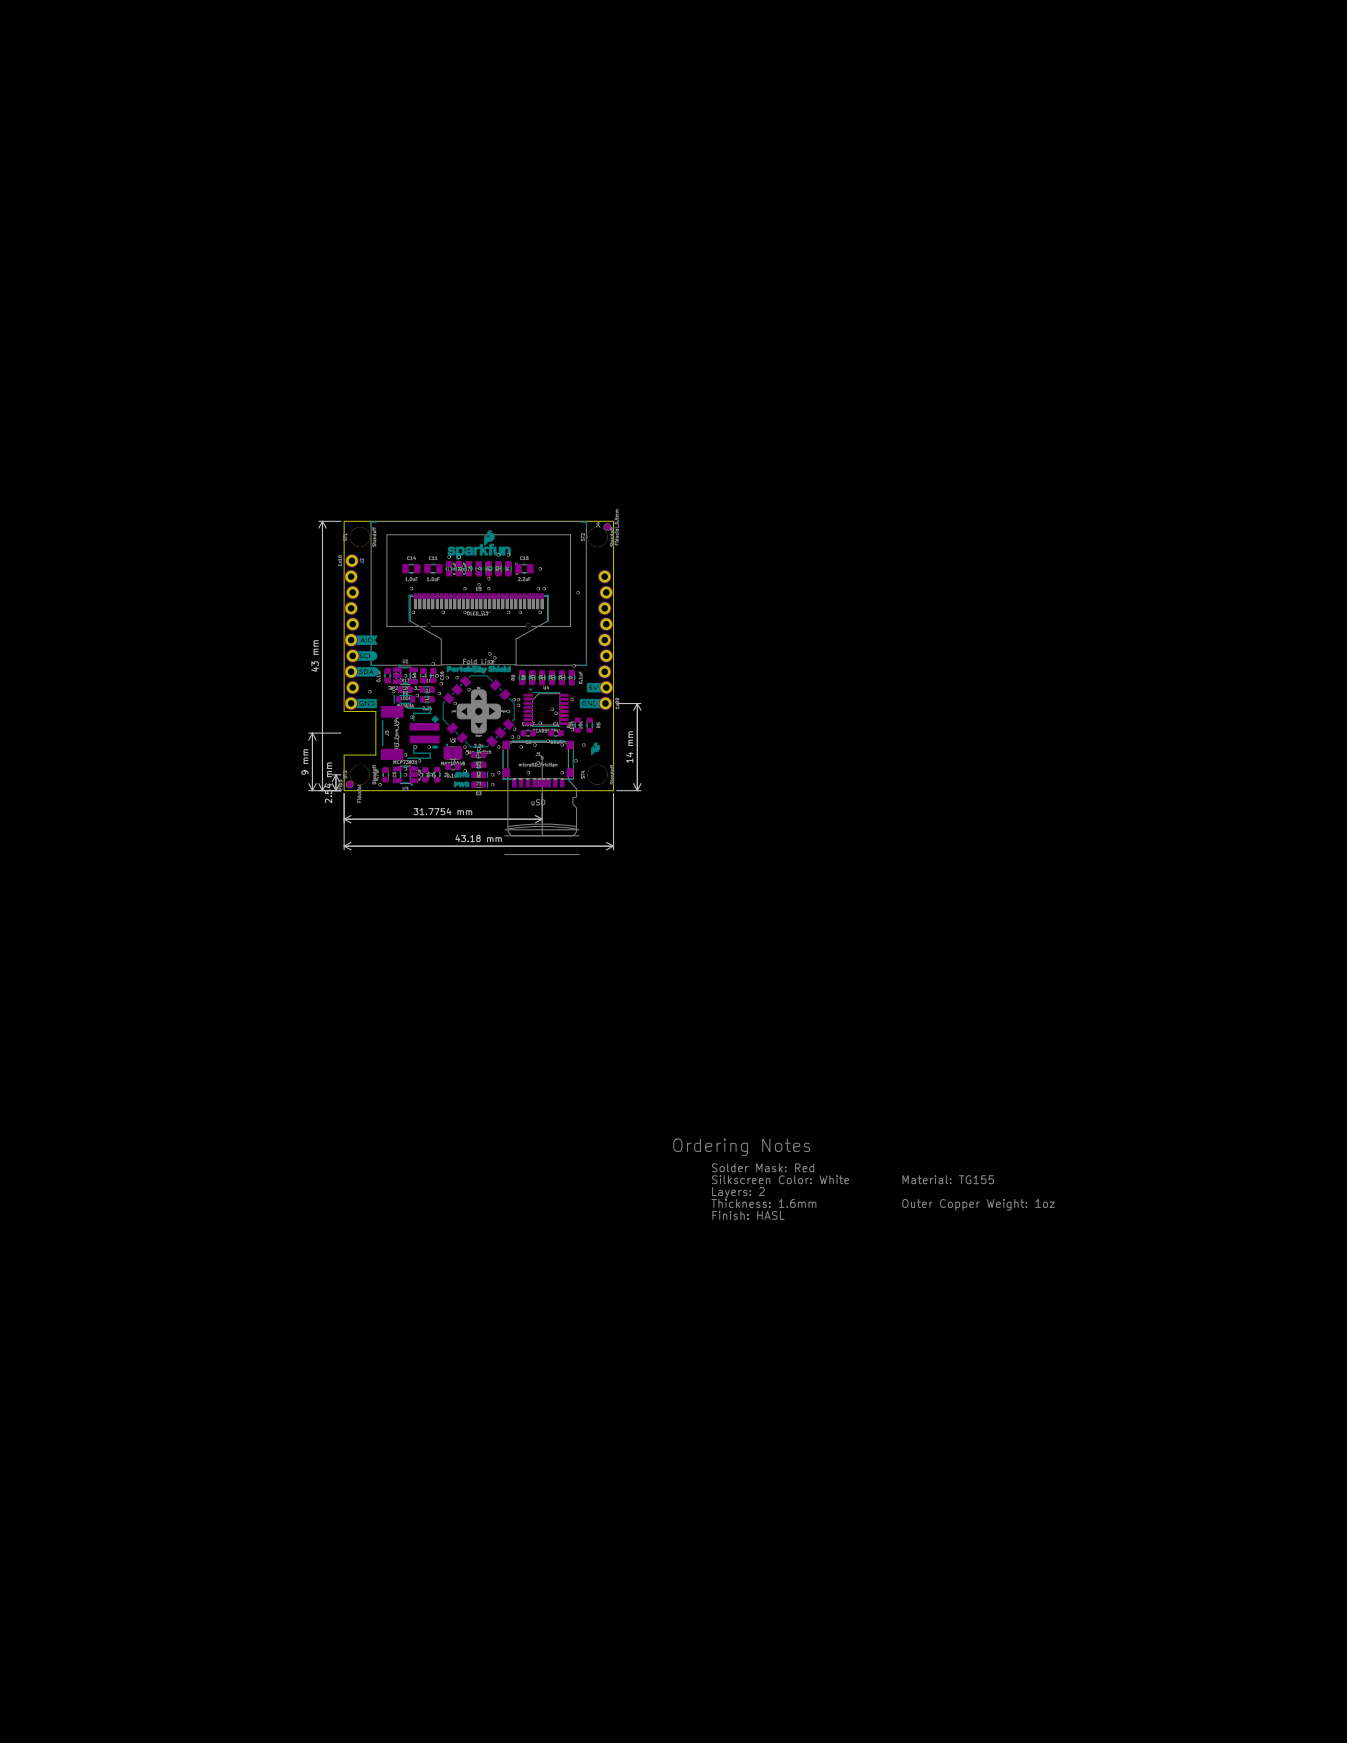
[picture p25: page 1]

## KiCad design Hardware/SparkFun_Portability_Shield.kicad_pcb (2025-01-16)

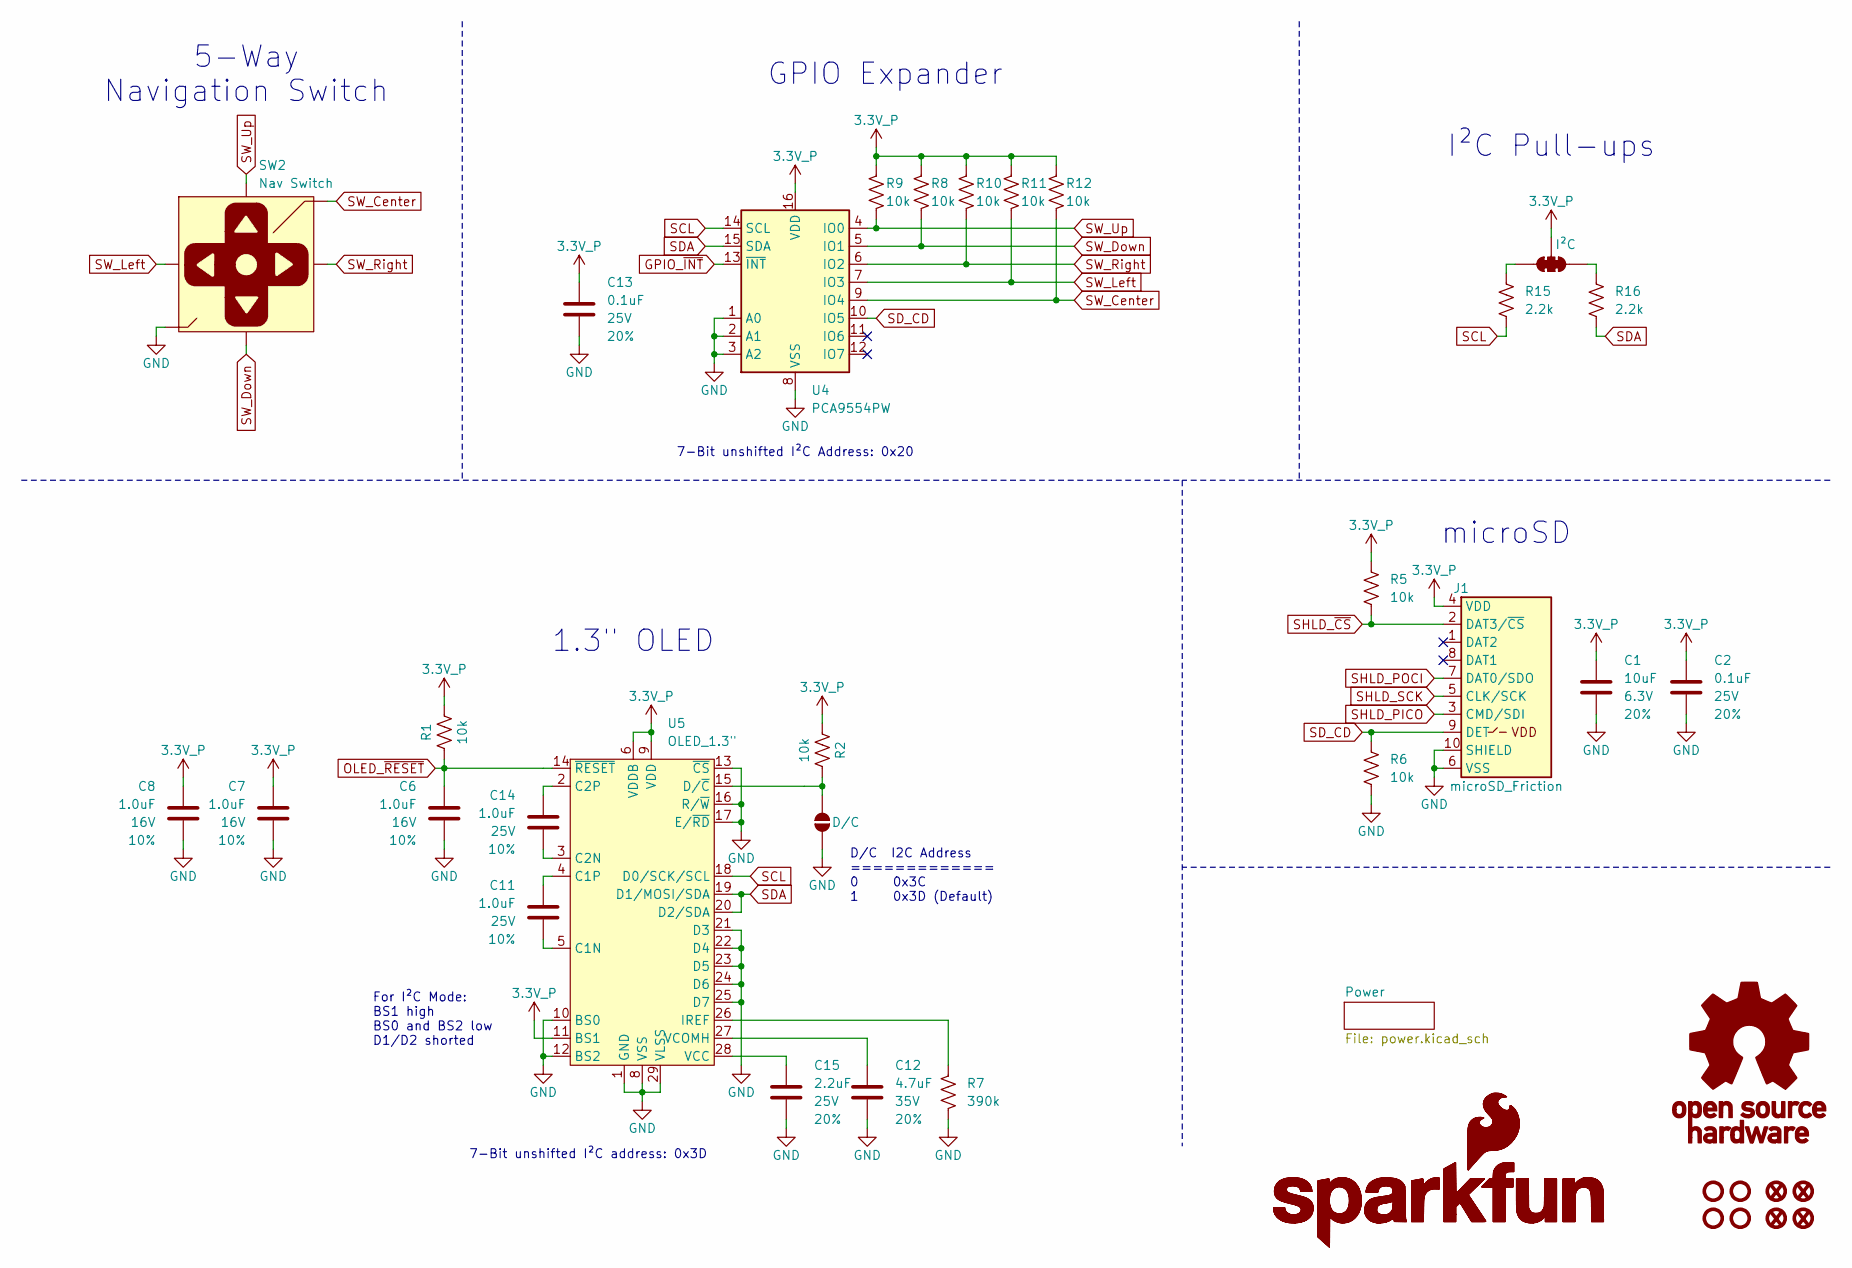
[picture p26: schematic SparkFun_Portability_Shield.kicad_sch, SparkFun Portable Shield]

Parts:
C1: 10uF; C_0603_1608Metric; Voltage 6.3V; Tolerance 20%
C2, C13: 0.1uF; C_0603_1608Metric; Voltage 25V; Tolerance 20%
C6, C7, C8: 1.0uF; C_0603_1608Metric; Voltage 16V; Tolerance 10%
C11, C14: 1.0uF; C_0805_2012Metric; Voltage 25V; Tolerance 10%
C12: 4.7uF; C_0603_1608Metric; Voltage 35V; Tolerance 20%
C15: 2.2uF; C_0805_2012Metric; Voltage 25V; Tolerance 20%
FID1, FID2, FID3, FID4: Fiducial_0.5mm; Fiducial_0.5mm_Mask1mm
G1: OSHW_Logo; Creative_Commons_License
G3: SparkFun_Logo
G5: SparkFun_Logo; SparkFun_Logo_8mm
J1: microSD_Friction; microSD_Friction_Fit_Common
JP2: D/C; Jumper_2_NO
JP4: I²C; Jumper_3_NC-2_Trace
R1, R2, R5, R6, R8, R9, R10, R11, R12: 10k; R_0603_1608Metric
R7: 390k; R_0603_1608Metric
R15, R16: 2.2k; R_0603_1608Metric
ST1, ST2, ST3, ST4: Standoff
SW2: Nav Switch; Navigation_SMD_7.5x7.5mm
U4: PCA9554PW; TSSOP-16_4.4x5mm_P0.65mm
U5: OLED_1.3"; OLED-1.3-128X64-Folded

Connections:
3.3V_P: C1.1, C2.1, C7.1, C8.1, C13.1, J1.4 (VDD), JP4.2 (C), R1.2, R2.1, R5.1, R8.2, R9.2, R10.2, R11.2, R12.2, U4.16 (VDD), U5.6 (VDDB), U5.9 (VDD), U5.11 (BS1); also elsewhere on the board
GND: C1.2, C2.2, C6.2, C7.2, C8.2, C12.2, C13.2, C15.2, J1.6 (VSS), J1.10 (SHIELD), JP2.1 (A), R6.2, R7.2, SW2.2 (GND), U4.1 (A0), U4.2 (A1), U4.3 (A2), U4.8 (VSS), U5.1 (GND), U5.8 (VSS), U5.10 (BS0), U5.12 (BS2), U5.13 (~CS), U5.16 (R/~W), U5.17 (E/~RD), U5.21 (D3), U5.22 (D4), U5.23 (D5), U5.24 (D6), U5.25 (D7), U5.29 (VLSS), U5.30 (GND); also elsewhere on the board
GPIO_~INT: U4.13 (~INT); also elsewhere on the board
unnamed: JP2.2 (B), R2.2, U5.15 (D/~C)
unnamed: JP4.1 (A), R16.1
unnamed: JP4.3 (B), R15.1
unnamed: C11.2, U5.5 (C1N)
unnamed: C11.1, U5.4 (C1P)
unnamed: C14.2, U5.3 (C2N)
unnamed: C14.1, U5.2 (C2P)
unnamed: R7.1, U5.26 (IREF)
unnamed: C15.1, U5.28 (VCC)
unnamed: C12.1, U5.27 (VCOMH)
OLED_~RESET: C6.1, R1.1, U5.14 (~RESET)
SCL: R15.2, U4.14 (SCL), U5.18 (D0/SCK/SCL); also elsewhere on the board
SDA: R16.2, U4.15 (SDA), U5.19 (D1/MOSI/SDA), U5.20 (D2/SDA); also elsewhere on the board
SD_CD: J1.9 (DET), R6.1, U4.10 (IO5)
SHLD_PICO: J1.3 (CMD/SDI); also elsewhere on the board
SHLD_POCI: J1.7 (DAT0/SDO); also elsewhere on the board
SHLD_SCK: J1.5 (CLK/SCK); also elsewhere on the board
SHLD_~CS: J1.2 (DAT3/~CS), R5.2; also elsewhere on the board
SW_Center: R12.1, SW2.5 (Center), U4.9 (IO4)
SW_Down: R8.1, SW2.3 (Down), U4.5 (IO1)
SW_Left: R11.1, SW2.1 (Left), U4.7 (IO3)
SW_Right: R10.1, SW2.4 (Right), U4.6 (IO2)
SW_Up: R9.1, SW2.6 (Up), U4.4 (IO0)

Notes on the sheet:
1.3" OLED
7-Bit unshifted I²C address: 0x3D
For I²C Mode: BS1 high BS0 and BS2 low D1/D2 shorted
D/C I2C Address ============= 0 0x3C 1 0x3D (Default)
5-Way Navigation Switch
GPIO Expander
7-Bit unshifted I²C Address: 0x20
microSD
I²C Pull-ups

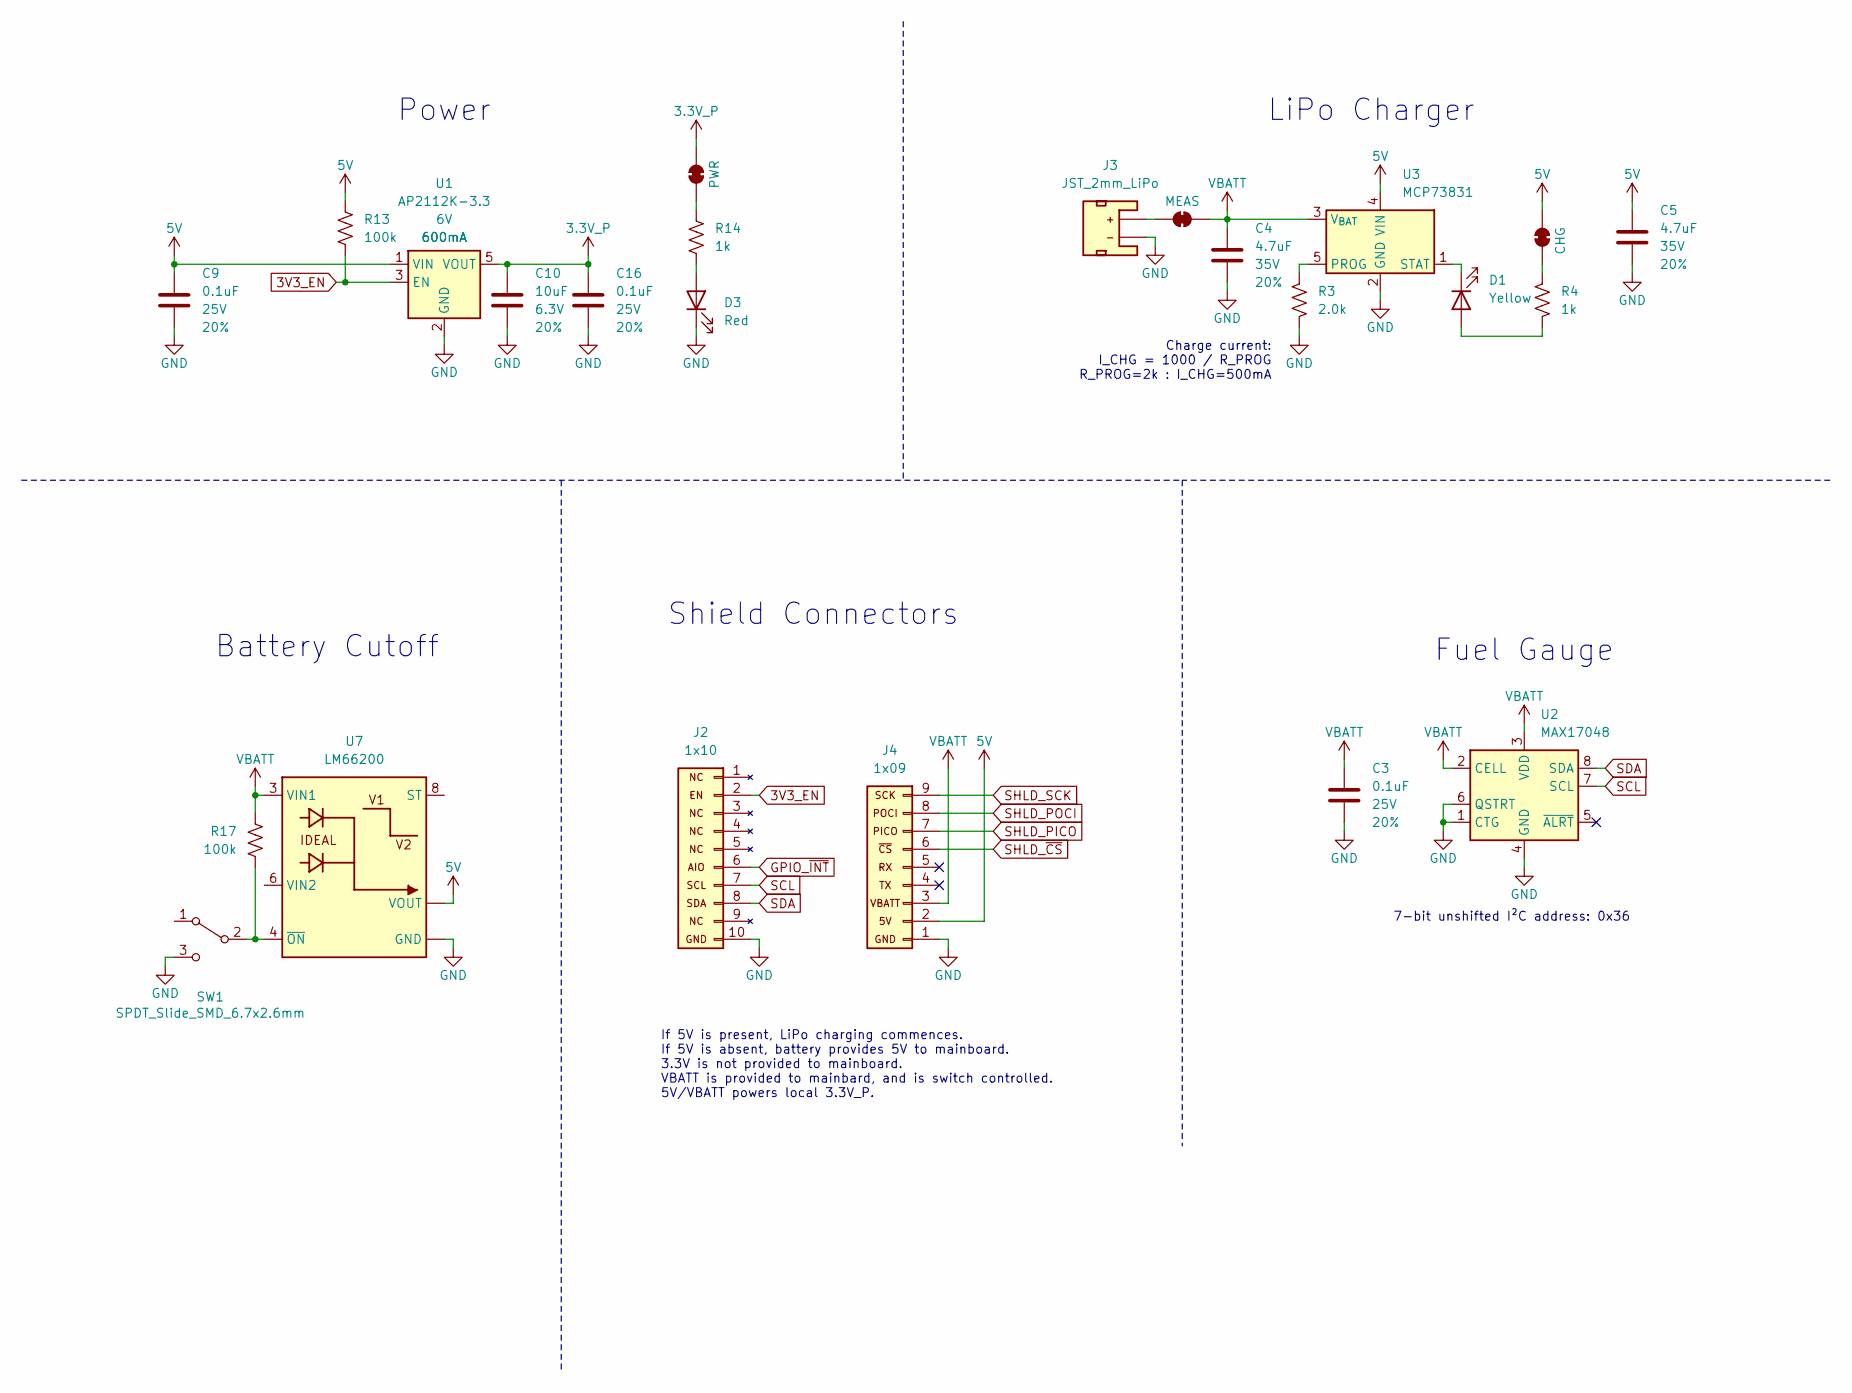
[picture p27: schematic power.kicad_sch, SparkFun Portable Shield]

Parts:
C3, C9, C16: 0.1uF; C_0603_1608Metric; Voltage 25V; Tolerance 20%
C4, C5: 4.7uF; C_0603_1608Metric; Voltage 35V; Tolerance 20%
C10: 10uF; C_0603_1608Metric; Voltage 6.3V; Tolerance 20%
D1: Yellow; LED_0603_1608Metric_Yellow
D3: Red; LED_0603_1608Metric_Red
J2: 1x10; 1x10_Locking
J3: JST_2mm_LiPo; JST_SMD_2.0mm-2
J4: 1x09; 1x09_Locking
JP1: CHG; Jumper_2_NC_Trace
JP3: PWR; Jumper_2_NC_Trace
JP5: MEAS; Jumper_2_PTH_SMD_Combo-NC
R3: 2.0k; R_0603_1608Metric
R4, R14: 1k; R_0603_1608Metric
R13, R17: 100k; R_0603_1608Metric
SW1: SPDT_Slide_SMD_6.7x2.6mm; Slide_SPST_SMD_6.7x2.6mm; Mrg Part# CUS-12B
U1: AP2112K-3.3; SOT23-5
U2: MAX17048; DFN-8
U3: MCP73831; SOT23-5
U7: LM66200; SOT-583-8

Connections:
3.3V_P: C10.1, C16.1, JP3.2 (B), U1.5 (VOUT); also elsewhere on the board
3V3_EN: J2.2, R13.2, U1.3 (EN)
5V: C5.1, C9.1, J4.2, JP1.2 (B), R13.1, U1.1 (VIN), U3.4 (VIN), U7.2 (VOUT), U7.7 (VOUT)
GND: C3.2, C4.2, C5.2, C9.2, C10.2, C16.2, D3.1 (K), J2.10, J3.1 (-), J4.1, R3.2, SW1.3 (C), U1.2 (GND), U2.1 (CTG), U2.4 (GND), U2.6 (QSTRT), U2.9 (GND), U3.2 (GND), U7.1 (GND), U7.5 (GND); also elsewhere on the board
GPIO_~INT: J2.6; also elsewhere on the board
unnamed: D1.2 (A), R4.1
unnamed: D1.1 (K), U3.1 (STAT)
unnamed: D3.2 (A), R14.2
unnamed: J3.2 (+), JP5.1 (A)
unnamed: JP1.1 (A), R4.2
unnamed: JP3.1 (A), R14.1
unnamed: R3.1, U3.5 (PROG)
unnamed: R17.2, SW1.2, U7.4 (~ON)
SCL: J2.7, U2.7 (SCL); also elsewhere on the board
SDA: J2.8, U2.8 (SDA); also elsewhere on the board
SHLD_PICO: J4.7; also elsewhere on the board
SHLD_POCI: J4.8; also elsewhere on the board
SHLD_SCK: J4.9; also elsewhere on the board
SHLD_~CS: J4.6; also elsewhere on the board
VBATT: C3.1, C4.1, J4.3, JP5.2 (B), R17.1, U2.2 (CELL), U2.3 (VDD), U3.3 (V_{BAT}), U7.3 (VIN1)

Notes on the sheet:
Power
Battery Cutoff
Charge current: I_CHG = 1000 / R_PROG R_PROG=2k : I_CHG=500mA
LiPo Charger
Shield Connectors
If 5V is present, LiPo charging commences. If 5V is absent, battery provides 5V to mainboard. 3.3V is not provided to mainboard. VBATT is provided to mainbard, and is switch controlled. 5V/VBATT powers local 3.3V_P.
7-bit unshifted I²C address: 0x36
Fuel Gauge

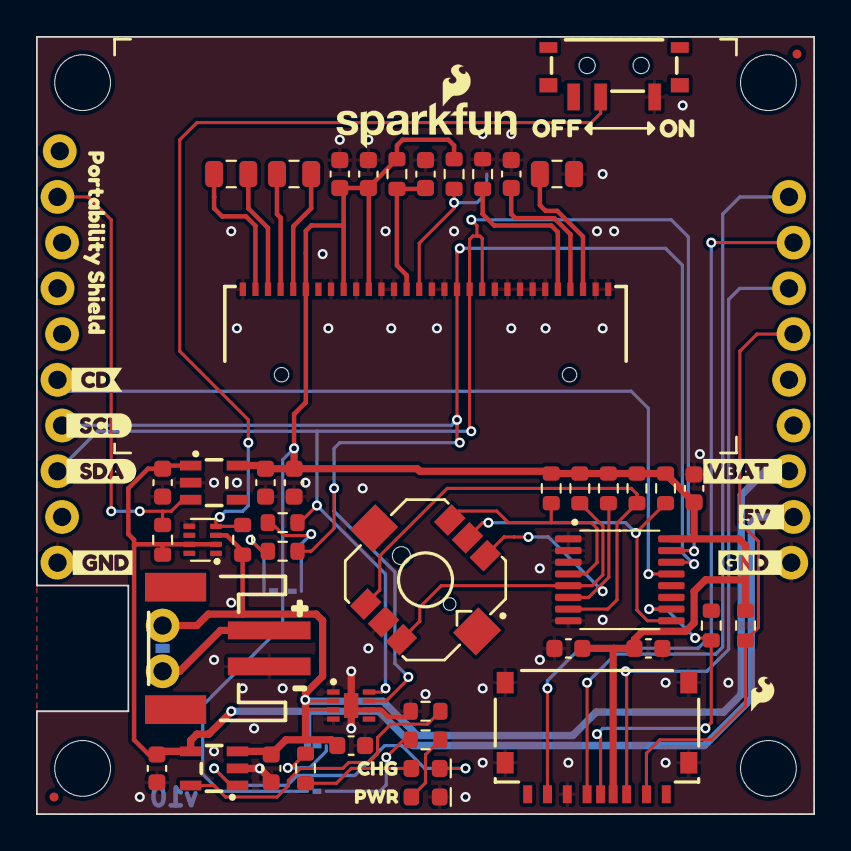
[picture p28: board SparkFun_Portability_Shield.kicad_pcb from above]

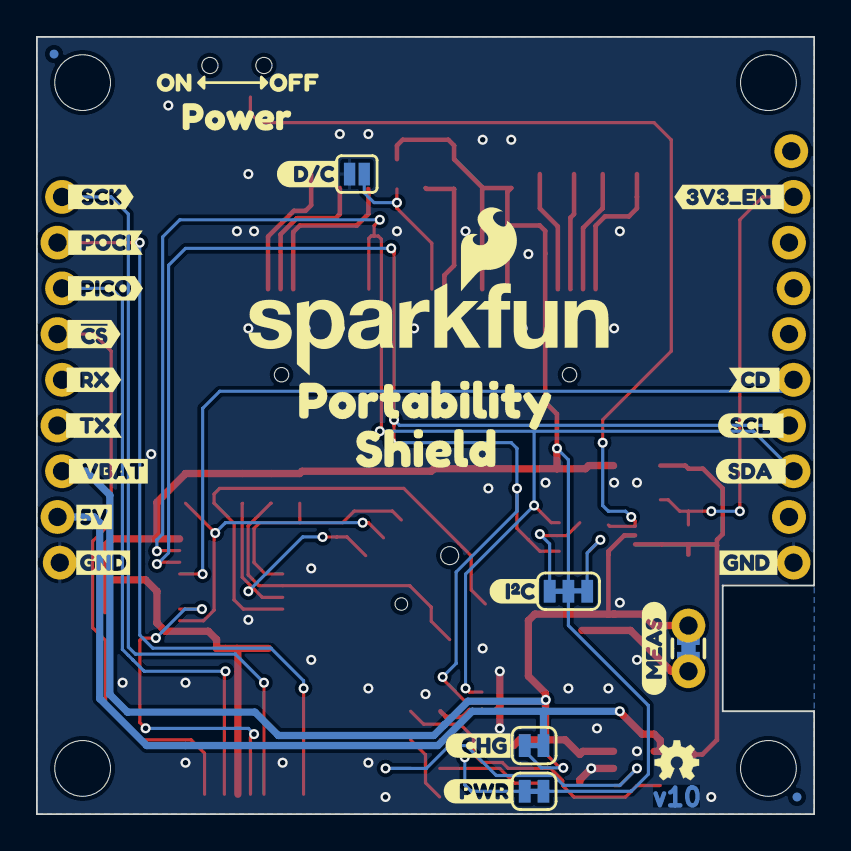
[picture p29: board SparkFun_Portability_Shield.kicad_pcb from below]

Board: 2 copper layers, 43.2 x 43.2 mm, 100 parts (32 on the bottom side), 37 nets.

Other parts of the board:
Ref**: Val**; OSHW_Logo_2.5mm
kibuzzard-66CAA9A5: G***; kibuzzard-66CAA9A5
kibuzzard-66CB37A9: G***; kibuzzard-66CB37A9
kibuzzard-66F0B700: G***; kibuzzard-66F0B700
kibuzzard-66F0B716: G***; kibuzzard-66F0B716
kibuzzard-66F0B764: G***; kibuzzard-66F0B764
kibuzzard-66F4A59B: G***; kibuzzard-66F4A59B
kibuzzard-66F4A593: G***; kibuzzard-66F4A593
kibuzzard-66F080CC: G***; kibuzzard-66F080CC
kibuzzard-66F080D6: G***; kibuzzard-66F080D6
kibuzzard-66F080E9: G***; kibuzzard-66F080E9
kibuzzard-66F080F8: G***; kibuzzard-66F080F8
kibuzzard-66F083A9: G***; kibuzzard-66F083A9
kibuzzard-66F083B5: G***; kibuzzard-66F083B5
kibuzzard-66F083BA: G***; kibuzzard-66F083BA
kibuzzard-66F085B1: G***; kibuzzard-66F085B1
kibuzzard-66F0824D: G***; kibuzzard-66F0824D
kibuzzard-66F0833D: G***; kibuzzard-66F0833D
kibuzzard-66F0844F: G***; kibuzzard-66F0844F
kibuzzard-66F0853A: G***; kibuzzard-66F0853A
kibuzzard-66F08248: G***; kibuzzard-66F08248
kibuzzard-66F08337: G***; kibuzzard-66F08337
kibuzzard-66F08463: G***; kibuzzard-66F08463
kibuzzard-66F08559: G***; kibuzzard-66F08559
kibuzzard-66F08561: G***; kibuzzard-66F08561
kibuzzard-66F08589: G***; kibuzzard-66F08589
kibuzzard-66F08591: G***; kibuzzard-66F08591
kibuzzard-66F08598: G***; kibuzzard-66F08598
kibuzzard-66F37954: G***; kibuzzard-66F37954
kibuzzard-673B98BA: G***; kibuzzard-673B98BA
kibuzzard-673B999B: G***; kibuzzard-673B999B
kibuzzard-673B9939: G***; kibuzzard-673B9939
kibuzzard-673B9961: G***; kibuzzard-673B9961
kibuzzard-673B9979: G***; kibuzzard-673B9979
kibuzzard-67140B1C, kibuzzard-67140B1C#2: G***; kibuzzard-67140B1C
kibuzzard-67140B31, kibuzzard-67140B31#2: G***; kibuzzard-67140B31
kibuzzard-67140CF9: G***; kibuzzard-67140CF9

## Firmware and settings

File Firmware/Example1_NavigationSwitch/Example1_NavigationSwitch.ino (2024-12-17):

/*
  Read the 5-way switch and card detect on the Portability Shield
  By: Nathan Seidle
  SparkFun Electronics
  Date: November 24th, 2024
  License: This code is public domain but you buy me a drink if you use this
  and we meet someday (Drink license).
  Feel like supporting our work? Buy a board from SparkFun!
  https://www.sparkfun.com/products/27510

  This example demonstrates how to read the 5-way nav switch and detect if the SD card is inserted.
  The !INT pin of the GPIO expander IC (PCA9554) triggers an interrupt any time a button is pressed or
  an SD card is inserted/removed.

  Hardware Connections:
  Connect the Portability shield to the RTK Postcard or other controller board
  Open output window at 115200bps
  Press button on navigation switch
*/

#include <SparkFun_I2C_Expander_Arduino_Library.h> // Click here to get the library: http://librarymanager/All#SparkFun_I2C_Expander_Arduino_Library

SFE_PCA95XX io(PCA95XX_PCA9554); // Create an instance with the PCA9554 IC

int gpioExpander_up = 0;
int gpioExpander_down = 1;
int gpioExpander_right = 2;
int gpioExpander_left = 3;
int gpioExpander_center = 4;
int gpioExpander_cardDetect = 5;

int gpioExpander_interrupt = 14; //INT of PCA9554 is connected to ESP14. Goes low when button is pressed.

bool buttonPressed = false;

void IRAM_ATTR gpioExpanderISR()
{
  buttonPressed = true;
}

void setup()
{
  Serial.begin(115200);
  delay(250);
  Serial.println("Portability Shield Example");

  Wire.begin(7, 20); //SDA, SCL. I2C0 on Portability Shield

  // Initialize the PCA95xx with its default I2C address
  if (io.begin() == false)
  {
    Serial.println("PCA9554 not detected. Please check wiring. Freezing...");
    while (1)
      ;
  }
  Serial.println("Portability Shield online!");

  pinMode(gpioExpander_interrupt, INPUT_PULLUP);

  io.pinMode(gpioExpander_up, INPUT);
  io.pinMode(gpioExpander_down, INPUT);
  io.pinMode(gpioExpander_left, INPUT);
  io.pinMode(gpioExpander_right, INPUT);
  io.pinMode(gpioExpander_center, INPUT);
  io.pinMode(gpioExpander_cardDetect, INPUT);

  uint8_t currentState = io.getInputRegister() & 0b00111111; //Ignore unconnected GPIO6/7
  if (currentState & 0b00100000)
    Serial.println("SD Card detected");
  else
    Serial.println("No card detected");

  //Setup interrupt service routine (ISR)
  attachInterrupt(gpioExpander_interrupt, gpioExpanderISR, CHANGE);
}

void loop()
{
  if (buttonPressed == true)
  {
    //Get all the pins in one read
    uint8_t currentState = io.getInputRegister() & 0b00111111; //Ignore unconnected GPIO6/7

    // Pins are pulled high so when we see low, button is being pressed
    if ((currentState & (1 << gpioExpander_up)) == 0)
      Serial.print("Up");
    if ((currentState & (1 << gpioExpander_down)) == 0)
      Serial.print("Down");
    if ((currentState & (1 << gpioExpander_left)) == 0)
      Serial.print("Left");
    if ((currentState & (1 << gpioExpander_right)) == 0)
      Serial.print("Right");
    if ((currentState & (1 << gpioExpander_center)) == 0)
      Serial.print("Center");

    Serial.println();

    buttonPressed = false;
  }

  delay(100);
}

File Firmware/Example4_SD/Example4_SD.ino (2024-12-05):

/*
  Attempt to mount an SD card and analyze the type of card
  By: Nathan Seidle
  SparkFun Electronics
  Date: November 24th, 2024
  License: This code is public domain but you buy me a drink if you use this
  and we meet someday (Drink license).
  Feel like supporting our work? Buy a board from SparkFun!
  https://www.sparkfun.com/products/27510

  Hardware Connections:
  Connect the Portability shield to the RTK Postcard or other controller board
  Insert a microSD card into the socket. Cards up to 512GB should work.
  Open output window at 115200bps
*/
#include "SdFat.h"  // Click here to get the library: http://librarymanager/All#SdFat_SDXC by Bill Greiman
#include "sdios.h"

int pin_spiSCK = 32;
int pin_spiPICO = 26; //microSD SDI
int pin_spiPOCI = 25; //microSD SDO
int pin_microSD_CS = 27;

#define SD_CONFIG SdSpiConfig(pin_microSD_CS, SHARED_SPI, SD_SCK_MHZ(16))
//#define SD_CONFIG SdSpiConfig(pin_microSD_CS, DEDICATED_SPI, SD_SCK_MHZ(16))

const int8_t DISABLE_CS_PIN = -1;

//------------------------------------------------------------------------------
SdFs sd;
cid_t cid;
csd_t csd;
scr_t scr;
uint8_t cmd6Data[64];
uint32_t eraseSize;
uint32_t ocr;
static ArduinoOutStream cout(Serial);
//------------------------------------------------------------------------------
void cidDmp() {
  cout << F("\nManufacturer ID: ");
  cout << uppercase << showbase << hex << int(cid.mid) << dec << endl;
  cout << F("OEM ID: ") << cid.oid[0] << cid.oid[1] << endl;
  cout << F("Product: ");
  for (uint8_t i = 0; i < 5; i++) {
    cout << cid.pnm[i];
  }
  cout << F("\nRevision: ") << cid.prvN() << '.' << cid.prvM() << endl;
  cout << F("Serial number: ") << hex << cid.psn() << dec << endl;
  cout << F("Manufacturing date: ");
  cout << cid.mdtMonth() << '/' << cid.mdtYear() << endl;
  cout << F("CID HEX: ");
  hexDmp(&cid, sizeof(cid));
}
//------------------------------------------------------------------------------
void clearSerialInput() {
  uint32_t m = micros();
  do {
    if (Serial.read() >= 0) {
      m = micros();
    }
  } while (micros() - m < 10000);
}
//------------------------------------------------------------------------------
void csdDmp() {
  eraseSize = csd.eraseSize();
  cout << F("\ncardSize: ") << 0.000512 * csd.capacity();
  cout << F(" MB (MB = 1,000,000 bytes)\n");

  cout << F("flashEraseSize: ") << int(eraseSize) << F(" blocks\n");
  cout << F("eraseSingleBlock: ");
  if (csd.eraseSingleBlock()) {
    cout << F("true\n");
  } else {
    cout << F("false\n");
  }
  cout << F("dataAfterErase: ");
  if (scr.dataAfterErase()) {
    cout << F("ones\n");
  } else {
    cout << F("zeros\n");
  }
  cout << F("CSD HEX: ");
  hexDmp(&csd, sizeof(csd));
}
//------------------------------------------------------------------------------
void errorPrint() {
  if (sd.sdErrorCode()) {
    cout << F("SD errorCode: ") << hex << showbase;
    printSdErrorSymbol(&Serial, sd.sdErrorCode());
    cout << F(" = ") << int(sd.sdErrorCode()) << endl;
    cout << F("SD errorData = ") << int(sd.sdErrorData()) << dec << endl;
  }
}
//------------------------------------------------------------------------------
void hexDmp(void* reg, uint8_t size) {
  uint8_t* u8 = reinterpret_cast<uint8_t*>(reg);
  cout << hex << noshowbase;
  for (size_t i = 0; i < size; i++) {
    cout << setw(2) << setfill('0') << int(u8[i]);
  }
  cout << dec << endl;
}
//------------------------------------------------------------------------------
bool mbrDmp() {
  MbrSector_t mbr;
  bool valid = true;
  if (!sd.card()->readSector(0, (uint8_t*)&mbr)) {
    cout << F("\nread MBR failed.\n");
    errorPrint();
    return false;
  }
  cout << F("\nSD Partition Table\n");
  cout << F("part,boot,bgnCHS[3],type,endCHS[3],start,length\n");
  for (uint8_t ip = 1; ip < 5; ip++) {
    MbrPart_t* pt = &mbr.part[ip - 1];
    if ((pt->boot != 0 && pt->boot != 0X80) ||
        getLe32(pt->relativeSectors) > csd.capacity()) {
      valid = false;
    }
    cout << int(ip) << ',' << uppercase << showbase << hex;
    cout << int(pt->boot) << ',';
    for (int i = 0; i < 3; i++) {
      cout << int(pt->beginCHS[i]) << ',';
    }
    cout << int(pt->type) << ',';
    for (int i = 0; i < 3; i++) {
      cout << int(pt->endCHS[i]) << ',';
    }
    cout << dec << getLe32(pt->relativeSectors) << ',';
    cout << getLe32(pt->totalSectors) << endl;
  }
  if (!valid) {
    cout << F("\nMBR not valid, assuming Super Floppy format.\n");
  }
  return true;
}
//------------------------------------------------------------------------------
void dmpVol() {
  cout << F("\nScanning FAT, please wait.\n");
  int32_t freeClusterCount = sd.freeClusterCount();
  if (sd.fatType() <= 32) {
    cout << F("\nVolume is FAT") << int(sd.fatType()) << endl;
  } else {
    cout << F("\nVolume is exFAT\n");
  }
  cout << F("sectorsPerCluster: ") << sd.sectorsPerCluster() << endl;
  cout << F("fatStartSector:    ") << sd.fatStartSector() << endl;
  cout << F("dataStartSector:   ") << sd.dataStartSector() << endl;
  cout << F("clusterCount:      ") << sd.clusterCount() << endl;
  cout << F("freeClusterCount:  ");
  if (freeClusterCount >= 0) {
    cout << freeClusterCount << endl;
  } else {
    cout << F("failed\n");
    errorPrint();
  }
}
//------------------------------------------------------------------------------
void printCardType() {
  cout << F("\nCard type: ");

  switch (sd.card()->type()) {
    case SD_CARD_TYPE_SD1:
      cout << F("SD1\n");
      break;

    case SD_CARD_TYPE_SD2:
      cout << F("SD2\n");
      break;

    case SD_CARD_TYPE_SDHC:
      if (csd.capacity() < 70000000) {
        cout << F("SDHC\n");
      } else {
        cout << F("SDXC\n");
      }
      break;

    default:
      cout << F("Unknown\n");
  }
}
//------------------------------------------------------------------------------
void printConfig(SdSpiConfig config) {
  if (DISABLE_CS_PIN < 0) {
    cout << F(
        "\nAssuming the SD is the only SPI device.\n"
        "Edit DISABLE_CS_PIN to disable an SPI device.\n");
  } else {
    cout << F("\nDisabling SPI device on pin ");
    cout << int(DISABLE_CS_PIN) << endl;
    pinMode(DISABLE_CS_PIN, OUTPUT);
    digitalWrite(DISABLE_CS_PIN, HIGH);
  }
  cout << F("\nAssuming the SD chip select pin is: ") << int(config.csPin);
  cout << F("\nEdit SD_CS_PIN to change the SD chip select pin.\n");
}
//------------------------------------------------------------------------------
void printConfig(SdioConfig config) {
  (void)config;
  cout << F("Assuming an SDIO interface.\n");
}
//-----------------------------------------------------------------------------
void setup() {
  Serial.begin(115200);
  delay(250);
  Serial.println("SPI test");

  SPI.begin(pin_spiSCK, pin_spiPOCI, pin_spiPICO);

  cout << F("SdFat version: ") << SD_FAT_VERSION_STR << endl;
  printConfig(SD_CONFIG);
}
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

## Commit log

2024-09-23 Add ignore.
    [SparkFun_RTK_Postcard_Portable_Shield.kicad_pcb]
2024-09-25 Change to dedicated header format.
    [SparkFun_RTK_Postcard_Portable_Shield.kicad_pcb, SparkFun_RTK_Postcard_Portable_Shield.kicad_sch, power.kicad_sch]
2024-09-25 File rename.
    [SparkFun_RTK_Postcard_Portability_Shield.kicad_pcb, SparkFun_RTK_Postcard_Portability_Shield.kicad_sch]
2024-09-25 Route board
    [SparkFun_RTK_Postcard_Portability_Shield.kicad_pcb]
2024-09-25 File rename
    [SparkFun_Portability_Shield.kicad_pcb, SparkFun_Portability_Shield.kicad_sch]
2024-11-19 Fix nav switch. Adjust silk. Update to v10.
    [SparkFun_Portability_Shield.kicad_pcb, SparkFun_Portability_Shield.kicad_sch]
2024-11-20 Bones of the documentation
    Initial pass to get the framework in place
2024-11-21 Update I2C address on PCA9554
    [SparkFun_Portability_Shield.kicad_pcb, SparkFun_Portability_Shield.kicad_sch]
2024-12-05 Fix ex 4 to work with latest SdFat library version
    [Example4_SD.ino]
2024-12-10 Update OLED model
    [SparkFun_Portability_Shield.kicad_pcb]
2024-12-10 Add LM66200 battery switch
    [power.kicad_sch]
2024-12-17 Update pin numbers to match production hardware
2025-01-16 Update directional pad FP
    [SparkFun_Portability_Shield.kicad_pcb]
2026-02-16 Added .step files for printing a thicker enclosure
    Notes: Thicker Housing Enclosures for the SparkFun RTK Postcard and Portability Shield combination
    There are two .step files (depending on how you connect the two modules):
    -------------------------
    Housing 2 v10 cc1-3.3mm.step (extra 3.3mm thick)
    - if soldering the two boards together with a set of male headers with just enough gap for a battery
    - the minimal thickness is a nice feature
    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

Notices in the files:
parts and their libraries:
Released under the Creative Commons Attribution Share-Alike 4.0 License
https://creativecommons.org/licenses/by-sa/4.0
